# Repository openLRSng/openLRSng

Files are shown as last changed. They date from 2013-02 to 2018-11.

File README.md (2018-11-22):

openLRSng
=========

My fork of openLRS code (based on thUndeadMod of openLRS)

More information at http://openlrsng.org

CONFIGURATOR UTILITY / BINARY FIRMWARE NOTE:
============================================
  This software should be used in source form only by expert users, for normal use 'binary' firmwares can be uploaded and configured by free configuration software available for Windows/Mac/Linux from Chrome web store.

  http://goo.gl/iX7dJx

  Binary firmware images are also available from

  https://openlrsng.org/releases/

TRANSMITTER HW:
===============
  - TX_BOARD_TYPE 0 (Arduino Mini/nano 328 16MHz)
    - Flytron openLRS M1 (100mW) TX

  - TX_BOARD_TYPE 2 (Arduino Mini/nano 328 16MHz)
    - Flytron openLRS M2 (100mW)/M3(1W) TX
    - OrangeRX UHF TX unit

  - TX_BOARD_TYPE 3 (RX module acting as TX) (Arduino Mini/nano 328 16MHz)
    - Flytron openLRS RX v2
    - OrangeRX UHF RX
    - HawkEye openLRS RX

    - connect PPM input to 5th slot from left (channel 4)
    - button between ground and 4th slot from left (ch3)
    - buzzer via transistor on 3rd slot (ch2) (active high)

  - TX_BOARD_TYPE 4 (Arduino Mini/nano 328 16MHz)
    - openLRSngTX ('kha' or DIY based on ngTX schematics)
    - HawkEye OpenLRSng TX

  - TX_BOARD_TYPE 5 (RX as TX) (Arduino Mini/nano 328 16MHz)
    - DTFUHF/HawkEye 4ch/6ch RX

  - TX_BOARD_TYPE 6 (Arduino Leonardo)
    - DTFUHF/HawkEye deluxe TX

  - TX_BOARD_TYPE 7 (RX as TX)
    - Brotronics PowerTowerRX

  - RX_BOARD_TYPE 8 (RX as TX)
    - openLRSng microRX

RECEIVER HW:
============
  - RX_BOARD_TYPE 2 (TX module as RX) (328P 16MHz)

  - RX_BOARD_TYPE 3 (Arduino Mini/nano 328 16MHz)
    - Flytron openLRS RX
    - OrangeRX UHF RX (NOTE both LEDs are RED!!)
    - HawkEye OpenLRS RX

  - RX_BOARD_TYPE 5 (Arduino Mini/nano 328 16MHz)
    - DTFUHF/HawkEye 4ch/6ch RX

  - RX_BOARD_TYPE 7
    - Brotronics PowerTowerRX

  - RX_BOARD_TYPE 8
    - openLRSng microRX

  Receiver pin functiontions are mapped using the configurator or CLI interface.

SOFTWARE CONFIGURATION:
=======================
  Only hardware related selections are done in the openLRSng.ino (Arduino) or platformio.ini (VSCode/PlatformIO).

  Run time configuration is done by connecting to the TX module (which is put into binding mode) with serial terminal. For best restults use real terminal program like Putty, TeraTerm, minicom(Linux) but it is possible to use Arduino Serial Monitor too.
  Sending '<CR>' (enter) will enter the menu which will guide further. It should be noted that doing edits will automatically change 'RF magic' to force rebinding, if you want to use a specific magic set that using the command (and further automatic changes are ceased for the edit session).

  Datarates are: 0==4800bps 1==9600bps 2==19200bps 3==57600bps 4==125kbps

  Refer to http://openlrsng.org

UPLOADING:
==========
Use a 3v3 FTDI (or other USB to TTL serial adapter) and Arduino >= 1.0.

  o set board to "Arduino Pro or Pro Mini (5V, 16MHz) w/ atmega328" (yes it runs really on 3v3 but arduino does not need to know that)

  o define COMPILE_TX and upload to TX module

  o comment out COMPILE_TX and upload to RX

  o for deluxeTX "arduino boardtype" must be set to "Leonardo"

GENERATED FIRMWARE FILES:
=========================
Makefile generates TX/RX firmware files for each frequency 433/868/915 as well as all hardware types [RX/TX]-[#].hex.

The "*-bl.hex" files contain bootloader and can be used when flashing via ICSP.
  o 328p model (all but type 6) use optiboot bootloader and thus needs fuses set to: Low: FF High: DE Ext: 05.
  o type 6 uses 'caterina' and fuses should be set to: Low: FF High: D8 Ext: CB.

USERS GUIDE
===========

Please refer to http://openlrsng.org (->wiki)

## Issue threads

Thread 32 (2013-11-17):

Selecting Output Power via RC Channel?

TobiasBales, 2013-11-17:
After using switching from EzUHF to a hawkeye lrs system
using openlrsng there is one thing I am missing.
Being able to use a switch to select between 2 (or 3) output power modes.

Is there an interest in adding this and getting it into the main repo?
If so I would probably do that.

The idea is to have a 2 or 3 position switch (I would prefer 3) to switch between
200mW, 600mW and 1W which can be useful to recover the plane in case of a failsafe etc.

Any opinions on this?

csurf, 2018-01-09:
@mikeller
we could probably get this setup, but I'm not sure if it's worth it. I personally wouldn't have a need for this, but others might.

It appears that your multiproto has the ability to change RF power, so perhaps legacy users might find something like this useful. dunno...

thoughts?

mikeller, 2018-01-10:
Yeah, I think this has mostly been superseded by the Multiprotocol support. I think we should close this.

csurf, 2018-01-10:
agreed.

geofrancis, 2018-01-10:
Power switching is already supported by a switch on the module itsself.

marcmerlin, 2018-01-10:
@geofrancis and it doesn't work for what it's worth, at least if never worked for me.

mikeller, 2018-01-10:
@marcmerlin: It seems to be working well on the orangeRX modules - but you have to solder on your own switch for it.

These days, the most comfortable way for this is to use Multiprotocol, and use the menu on the TX to adjust your power.

geofrancis, 2018-01-10:
the problem is you cant change the PA power on the modules, your just changing the input to the PA, i made a module with adjustable power before, basically switching the PA between 3.3v and 6v, normally this would reboot the module but with a large capacitor it slowed down the voltage change enough that it could be switched on the fly.

Closed 2018-01-10.

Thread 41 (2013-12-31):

Improved beacon/buzzer idea

readerror67, 2013-12-31:
Beacon ET Phone Home

Idea:
Utilizing the 'call' button on an inexpensive handheld radio (Baofeng UV-5R for example) to trigger remote beacon and/or buzzer.

Implementation (This is under the assumption of a new battery backup, small 1s 300mah, more on this later):
1) RX loses PPM signal, enters failsafe then beacon mode.
2) In between 'beacons' the RX will listen on a specific channel (435.00MHz)
3) If the 'noise' or RSSI crosses a certain threshold, the beacon is re-transmitted within a short period of time after the 'call'.
4) Audible beep is fired off (using buzzer circuitry) after this beacon based on duration of the 'call', this is used to hone in on the location once you are somewhat close as the model may be in a bush not visible.

Benefits:
1) It would be much faster to get a bearing as to where to head direction wise since one can manually fire off the beacon, spin in circles until they feel they have a better idea where the model is located.
2) The audible 'beep' can be set on a threshold as to not waste power, if the 'call' is longer than 2 seconds, the buzzer circuitry is activated.

kh4, 2015-01-04:
I may give a shot at this today ;-)

kh4, 2015-01-04:
Implemented by 4669e8a

kh4, 2015-02-09:
Hmh the audible part needs to be done still...

csurf, 2018-01-05:
@readerror67
The 'ET'/interactive beacon was setup a long while back.
Can you go ahead and close this out?

Closed 2018-01-09.

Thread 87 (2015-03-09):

GPIO swap

stormjohn, 2015-03-09:
Forgive me I made this comment on a closed issue (#70). But if you will, I will repeat myself!
How common is the GPIO swap an issue? I have a Flytron M3 (1W) its struggling to make 100mW on my power meter with a 50 Ohm "dummy load" no matter what I try. I compiled with the latest 3.8 firmware.
Any help would be greatly appreciated.
Thank you.
Lyn.

kh4, 2015-03-09:
With correct hw type (2) selected the GPIO:s are proper the setting is only used for certain hardware types and is handled internally.

What powermeter you are using? Notably you should measure the 'peak' power not average since the transmission is 'pulsed'. For example with default settings the average power from Flytron M3 would be around 150mW. You can use the 'openLRSng_tester' to transmit continously.

stormjohn, 2015-03-10:
Thanks for the reply Kari.

I tested both with "Average" & "PEP" on my cheap SWR / PWR meter, ( my finances could not stretch to a Bird 43). Anyhow the Average is as I said 100mW and Peak is only slightly higher at 120mW! I don't think there is anything wrong with the meter as I tested my "Dragon Link" in the same manner and it's showing the expected 500mW output.
I did noticed the spectrum analyzer was giving a peak RSSI output of only 81 at 432MHz. This did surprise me as I adjusted the frequency in the configurator for the UK legal 458MHz band.
What I have also found even with a Diamond SRH771 antenna on the Tx I cannot use it. The Rx gives me an intermittent "blue" LED changing almost straight away to a solid "red" LED at just a few Cm's away. If the Tx was giving even a small output I surely should have had a reasonable signal at a few Cm's. I did find the best response was to fit a small omni pole to the Rx and the "dummy load" (the one that came with the "Dragon Link" for range testing) to the Tx. I could get >50 meters with full servo control and solid "blue" LED and no lost "packets". If I reverse the antennas i.e. put the "dummy load" on the Rx and the small antenna on the Tx I again loose any control at few Cm's with all "packets" lost (solid "red" LED).
Again any advice would be appreciated.

Lyn

fofi1, 2015-04-29:
Flytron's 1W transmitter uses only 3.3V supply for the RFM23BP. So the maximum Output Power is 350mW for this module.

Only at 6V it would deliver about 900mW of output power.

The RFM Modules only work great with Dipole antennas due to internal impedance matching to 50 ohm.

kh4, 2015-04-30:
You might have burned the RFM23 modules output stage, thus is quite common.

It can happen by no or bad antenna while it is transmitting or by static electricity charge to the antenna port. You can get RFM23BP modules for about 10 to 15USD.

stormjohn, 2015-06-29:
Hi Kari.

Sorry for the late response.

I would like to agree with you on this if it wasn’t for the fact that I have both the original Flytron and the HK orange “look alike” unit both rated at 1W. Both are giving me a similar output!

I have some experience using RF units and would like to think I have not powered them without the antenna fitted!

I now know that because of the on-board 3V3 supply I am at best only going to see 27dbm (Hope RF datasheet).

Both units are showing a similar reading on the power meter! That is nowhere near my “Dragon link” unit.

I understand if you are unable to devote time to this.

In the mean time I am completing a unit with a ATMega 328 and Hope RF RFM 23BP with the full 5V5 supply at the Vcc pin.

Kind regards

Lyn.

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

Timvrakas, 2015-06-30:
Just to let you know, you are not the only one having these problems... I
just finished a prototype run of USB dongle RFM23bp devices, and I cannot
get any range out of them! I can't tell if it's my inexperience or bad
luck, but they sure are finicky.
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

stormjohn, 2015-06-30:
Hi Tim.

Thanks for sharing.

I will let you know how I get on with the custom units.

Kind regards

Lyn

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

linuxslate, 2018-01-02:
Sorry;  I commented on the closed issue too.

I am building my own DIY hardware, and I am using BOARD_TYPE == 4, which has #define GPIO_SWAP.

I have GPIO0 connected to RX ON, and GPIO1 connected to TX ON. In other words, they are NOT Crossed. It is wired like I see everyone wiring RFM22B's.

Therefor I thought I did NOT need #define SWAP_GPIOS.

But then I looked at the code. In common.h, I see:

```
#ifdef SWAP_GPIOS
  spiWriteRegister(0x0b, 0x15);    // gpio0 RX State
  spiWriteRegister(0x0c, 0x12);    // gpio1 TX State
#else
  spiWriteRegister(0x0b, 0x12);    // gpio0 TX State
  spiWriteRegister(0x0c, 0x15);    // gpio1 RX State
```

The comments seem to indicate that if GPIO0 connected to RX ON, then I DO need SWAP_GPIO's.

Is the comment wrong or mis-leading?

Is 0x12 on or off? I have read the RFM23BP data sheet, and I still don't get it. Also, RX ON and TX ON are apparently active low.

Please help, as I have been messing with these both in software and hardware, and probably fried my module.  I have more on the way, but I do not want to install them without understanding this better.

--- Very confused.

linuxslate, 2018-01-02:
This is also unresolved in (Closed) issue 81.
https://github.com/openLRSng/openLRSng/issues/81

They are telling him to use BOARD_TYPE == 2, which does not have #define GPIO_SWAP, but both the schematic in that issue, and the photo show that the GPIO's are wired crossed (look at the feed throughs).

In the hopes of making this easy, I have even done some ascii art to try to make this clear.

```
If you have a RFM23BP, and the GPIO connections
are wired like this:

Looking at top (component side) of RFM23BP

 ______________
|   _______    |
|  |       |   |
|  |   |   |   |
G  G   V   R   T
P  P   C   X   X
I  I   C
O  O       O   O
1  0       N   N

Then DO/DO NOT use #define SWAP_GPIOS

If it is wired like this:

 __________
|   _______)___
|  |       |   |
|  |   |   |   |
G  G   V   R   T
P  P   C   X   X
I  I   C
O  O       O   O
1  0       N   N

Then DO NOT/DO use #define SWAP_GPIOS

```

If someone "in the know" could just edit it DO's/DO NOT's appropriately, it would really help.

This could even go at the beginning of hardware.h

csurf, 2018-01-02:
@linuxslate,
normal: GPIO0 ==>> TX pin
swapped: GPIO0 ==>> RX pin
so, add/remove the '#define SWAP_GPIOS' statement accordingly based on your connections.

the '0x12' & '0x15' values are binary/bitmap values meant to configure the GPIO registers in order to have them output the TX and RX states. These are fed into the TX_ANT and RX_ANT pins on the RFM module in order to put the antenna into either TX mode or RX mode.

See this datasheet for more info on register config:
https://www.silabs.com/documents/public/data-sheets/Si4430-31-32.pdf

csurf, 2018-01-05:
@mikeller
let's close this back out once @linuxslate responds with an 'ACK' for the above explanation...

linuxslate, 2018-01-05:
My DIY transmitter seems to be working with it wired like this:

```
______________
|   _______    |
|  |       |   |
|  |   |   |   |
G  G   V   R   T
P  P   C   X   X
I  I   C
O  O       O   O
1  0       N   N

```
... and #define SWAP_GPIOS  defined.

This seems to agree with csurf's explanation above.

So I am OK with closing this issue.  However; I think that the comments in the #ifdef SWAP_GPIOS section of common.h should be replaced with csurf's explanation:
```
normal: GPIO0 ==>> TX ON, GPIO1 ==> RX ON
swapped: GPIO0 ==>> RX ON, GPIO1 ==>TX ON
```
(Note that I changed the nomenclature to match the pin callouts in the RFM23BP datasheet.)

They should also be included as a comment at the top of hardware.h
The comment should probably include a line explaining that this is only for some boards with a RFM23BP.

Just suggestions.  I'm just a just a dumb user that likes to solder stuff and fly radio control.

csurf, 2018-01-05:
@linuxslate
ok, agreed, the comments will be added to hardware.h. I'll have to set it up on a separate 'hardware cleanup' branch where I'll start breaking up the hardware profile definitions into separate files.

BTW, @linuxslate, are you on IRC chat? You should come check out the  openlrs channel on freenode. It's pretty dead nowadays, but a few of us are still active on there sometimes, and it's easier to ask questions & discuss ideas there.

@mikeller
please grant me write access so I can start actively cleaning stuff up here on the repo...

linuxslate, 2018-01-30:
Believe it or not, there is still confusion on this.  See edited comment above.

Just updating for any DIY'ers or product designers that may still want to use this module.

jonathan2018, 2018-01-31:
#define SWAP_GPIOS. Wherecan   i can add it ?
#if (BOARD_TYPE == 3)
#if (__AVR_ATmega328P__ != 1) || (F_CPU != 16000000)
#warning Possibly wrong board selected, select Arduino Pro/Pro Mini 5V/16MHz w/ ATMega328
#endif

#if (COMPILE_TX == 1)
HardwareSerial *rcSerial = &Serial;

#define USE_ICP1 // use ICP1 for PPM input for less jitter

#define PPM_IN 8 // ICP1

#define TX_AIN0 A4 // SDA
#define TX_AIN1 A5 // SCL
#define TX_MODE1 11
#define TX_MODE2 12

#define BUZZER_ACT 6
#define BUZZER_PAS 3
#define BTN 7

linuxslate, 2018-01-31:
I am not sure *why* you would want to add it.
CAUTION:  Adding it can cause hardware damage.

If you are a DIY'er (Building or modifying your own hardware) you should correct the GPIO wiring, *not* add #define SWAP_GPIOS

If you are using a supported board, you should not have to add this, and if you do, hardware damage may result.

If you still feel you need to add it, it can be anyplace in the board definition, just make sure it is not inside of the #if (COMPILE_TX != 1)  #else structure, other wise you could end up with it defined for RX, and not for TX or vise-versa.  In this case, hardware damage would almost become a certainty because it will definitely be wrong for one.

The only board that uses it (== 4) puts it at the very end.

Closed 2018-01-09.

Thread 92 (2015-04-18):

Diversity doesn't switch

fofi1, 2015-04-18:
Hi,

After building and flashing my 2 Broversitys I recognized that the ANT_Detect Pin (PD7) stays low all the time. I have never seen it switching. Even if I disconnect the active Antenna it doesn't want to switch. It is the same with both Diversitys :( .

Is there any way to look up the rssi values of the two antennas? Is there any debug information i can use to look if the HF switch works correctly?

P.S: I'm very happy that Openlrsng now supports diversity (VERY VERY important when we fly down montains. Multipathing is extreme).

Have a nice day,
Florian from Germany

readerror67, 2015-04-19:
Hello Florian,

PD7 was actually put in place but is not actually used. I added it incase code was added to monitor the active antenna in OpenLRSng but this is not needed. R5 should not be populated as it will pull things down to ground.

There are also a few other troll parts that should be left unpopulated:
R9 - Resistor by LED (pulldown)
R18/R4 (Right under PPM)
R5 as covered above.

If you flash the BroversityRX firmware and have it bound the LEDs should both be blinking very quickly, it may look like they are both on but its actually switching between antennas during the pre-amble.

Also make sure you have diversity enabled on the TX, this will generate a slightly longer pre-amble which is used for the algorithm to select the best antenna.

fofi1, 2015-04-19:
Hi,

thanks for the fast response.  R5 is currently populated on my board. I will remove it and test it again next weekend.

Have a nice day :)

fofi1, 2015-04-29:
Hi,

With the removed Resistor R5 everything is working perfect. Thanks for your great support.

I hope i can make a rangetest tomorrow :)

Closed 2015-04-29.

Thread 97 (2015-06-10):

Taranis TX low power causing cleanflight receiver bar fluctuations

Ninjarev, 2015-06-10:
Dont know if anyone is having this problem..  When taranis transmitter drops to 7.8V using a LRS deluxe UHF transmitter module cleanflight has fluctuations in the channel bars in reciever tab. It gets worse as voltage drop gets lower. When it drops to 7.2V the UHF will not bind.  If I charge the radio back up to 8.4 volts it works fine..  Also note using a Sparky and the reviever is a mini DTF..

kh4, 2015-06-14:
Please check by having the TX module connected to PC while taranis is low power, open up the signal monitor tab an see if the bars are stable there.

Ninjarev, 2015-06-24:
Thanks for response I will check it next time battery is low

JIM

----- Original Message -----

From: Kari Hautio<mailto:notifications@github.com>

To: openLRSng/openLRSng<mailto:openLRSng@noreply.github.com>

Cc: Ninjarev<mailto:senshirev@msn.com>

Sent: Sunday, June 14, 2015 10:32 AM

Subject: Re: [openLRSng] Taranis TX low power causing cleanflight receiver bar fluctuations (#97)

Please check by having the TX module connected to PC while taranis is low power, open up the signal monitor tab an see if the bars are stable there.

—
Reply to this email directly or view it on GitHub<https://github.com/openLRSng/openLRSng/issues/97#issuecomment-111853262>.

csurf, 2018-01-09:
@Ninjarev,
did you ever get this tested and resolved? if so, please post back and close this issue out.

csurf, 2018-01-23:
no response, closing...

Closed 2018-01-23.

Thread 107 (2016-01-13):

speedup update freq by transmitting only changing channels

universam1, 2016-01-13:
AFAIK every channel is transmitted in order regardless whether its value has changed or not. Could we increase speed and/or range by transmitting only changing channels and submitting 'full' frames only from time to time?

The nature of RC is that during one cycle not all channels are going to change at once. Mostly maybe 2-3 channels only change, while other ch like AUX only in few seconds.

The idea is, regularly sent full frames, between only the changing ones.
I see following advantages:
- The active channels get automatically priority.
- Less channels altered the more bandwidth, up to almost full bandwidth for a single active channel
- it would be possible to transmit always all 16 channels, regardless if used or not, since they would take almost no air time!

For instance, every channel gets an ID, say 2-byte word with first 4 bits the address 0-15 and remaining 12 bit the value. The TX keeps track of last values and skips channels not changed. Of course on CPPM input there would be some trigger needed against jitter, but SBUS & co would be fine.
Every 500ms or so a full frame is sent to sync.
On RX side it would be a simple assigning of channels to array that do arrive.

If worst comes to worst, and the RX doesn't receive, probably this is not an issue, since as a pilot you would add more input if you are missing response which does implicitelly call a update fire of that channel.

What do you think about that?

Thank you!

mlyle, 2016-01-13:
There's a lot of delicate things that come into making a protocol which does this.  This isn't to say it can't be a win, but that it's nontrivial.

First, the receiver needs to be able to deterministically predict where the transmitter will be transmitting at a given time.  So the channel hop time needs to be predictable to the receiver no matter what the transmitter is trying to do.

Second, shorter frames are not always as much of a win as one might think, because of channel hop time, the preamble detector, etc.

Third, the effect of loss needs to be considered.  E.g. if someone clicks a "flight mode" switch which changes a FC from acro to attitude mode, and then immediately moves the pitch stick full forward, what are the consequences if the frame containing the "mode" change is lost but the pitch input is maintained?

ElectricRCAircraftGuy, 2016-01-13:
That's what I see too. The only way one can successfully implement what is
being proposed I think is to have two-way communication, where the receiver
responds to the sender with an acknowledgement packet, and the sender keeps
sending repeat information until the receiver acknowledges receipt of this
information. Otherwise, packet losses can be catastrophic. For one way
communication I don't see a way to avoid this hazard without sending every
channel every frame. This way,  lost packets have essentially no effect, as
the RC vehicle continues operating as commanded so long as the occasional
packet does get through.

Sincerely,

Gabriel Staples
www.ElectricRCAircraftGuy.com

(sent from my Android)
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

universam1, 2016-01-13:
Well, I dont think it is needed to change the hop time or change the frame lenght at all. I am thinking about to add a channel ID that helps the receiver determine which channel was sent. So no change needed to current transmission, just changing the data.

Also, the 'full frame' the one that contains all channels could be deterministically discovered or maybe even an adjustable setting. Or a fallback to 'syncronous' mode by the emergency button click...

Or, if we have 2-way communication, then sent back the CRC. If not correct, fall back to "syncronous" mode.

mlyle, 2016-01-13:
> Well, I dont think it is needed to change the hop time or change the frame lenght at all. I am thinking about to add a channel ID that helps the receiver determine which channel was sent. So no change needed to current transmission, just changing the data.

If you don't change the frame length, you'll be sending data at the present rate.  So what is the benefit from not sending all the channels?  Also the frame that contains all channels can be presumed to be longer...

universam1, 2016-01-14:
Indeed, the 5 bytes chunks made me think it is possible without altering the frame length which is obviously necessary...

I came accross this while working on FRSKY air protocol. Interestingly, that is actually what they're doing, sending active channels on a higher update rate than idle ones. Even more, they are also prioritizing more important telemetry frames. Obviously, it works.
They introduce a frame by a start and end byte + CRC, and channels by an ID. This is smart implemented, since it gives the TX full domain over what to send and how often, thus not requirering the RX to any special timing agreement.

Dont get me wrong, I dont want to propose FRSKY protocol nor mark OpenLRSng as not well done - I love to use OLRSng wherever possible, but I currently still prefer FRSKY for acro planes because of responsiveness.

Another benefit hence could be, that free airtime bandwidth could be granted between the serial data and the channels updates, dependent of needs.

I think it would be possible to lift OpenLRSng to a higher level with some airtime management like this.

DTFUHF, 2016-01-14:
That's interesting about the frsky protocol, I've looked at D8 and knew
they did telemetry scheduling due to the limited down link, but full frames
are sent on every uplink packet - same with PXX. Also - the frsky uplink is
only about 80Hz iirc, which makes PPM the bottleneck for system latency and
refresh - and openlrsng can easily beat

On Thu, Jan 14, 2016 at 4:47 AM, universam1 <notifications@github.com>
wrote:

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

universam1, 2016-01-14:
Not talking about the D8 or PXX  which is to the TX, but on the air code which is different.
You beat 80HZ update rate with the 19200 baud setting? I guess you mean 115200 baud that I would not consider stable.

DTFUHF, 2016-01-14:
I am referring to the over-the-air d8/16 protocol, working source can be
found in DeviationTX firmware.

From memory, openlrs at 19.2k, the 8 channel link is 71Hz, the 4+4 channel
link is higher

On Thu, Jan 14, 2016 at 7:14 AM, universam1 <notifications@github.com>
wrote:

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

universam1, 2016-01-14:
I checked, at 19200 with 8ch it is at 39hz, with 4+4 it is 42hz.
80hz would be a nice goal.
Am 14.01.2016 16:30 schrieb "DTFUHF" <notifications@github.com>:

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

DTFUHF, 2016-01-14:
Ah, right, I typically don't use telemetry :)

With telemetry off uplink rate is doubled.

On Thu, Jan 14, 2016 at 8:53 AM, universam1 <notifications@github.com>
wrote:

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

kh4, 2016-02-01:
I will keep this in mind if I do drastic changes to protocol.

As for now I am not going to do differential since it would mean differentiating the telemetry/nontelemetry modes significally.

Closed 2016-02-01.

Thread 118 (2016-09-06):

WIP: Serial PPM-in over native pins (PPMin)

universam1, 2016-09-06:
This is to give a heads up and request for guidance.

@mikeller and I are working successfully on adding Serial input with Multiprotocol, since the existing SUMD or SBUS protocols are facing dropping support on the controller side opentx/opentx/issues/2894
#### Multiprotocol via Hardware Serial

There is already a nice working and tested Multiprotocol implementation via the **HardwareSerial** port from @mikeller: openLRSng/openLRSng/pull/117
### Serial on native pins

The logical conclusion was whether it is possible to parse the native PPM-in pin via Software Serial which will bring benefits like
- **no soldering** required so plug and play
- configuration still accessible as before on the hardware serial
- no additional work then enabling digital transmission
- serial uplink still possible (APM f.e.)

It works! :smile:
After a lot of tuning and improvements as parity checks we are now up to 99.9% frame integrity!!
That means on 1/1000 frames there is one value "0" thus corrupt, this happens ~20sec. So far this is pretty awesome result given that it's Software Serial. (should be possible to filter this one frame out).

A working softserial implementation on its native pins you are welcome to test it here: **https://github.com/universam1/openLRSng/tree/Multi_with_SoftSerial**

Now I would appreciate some feedback where the stakeholder would like to go.
### custom "OLRS" protocol or Multiprotocol

As being said Multi over Softserial does already work 99.9% but there are some downsides of using Multiprotocol (changing standard to come, no ID for OLRS, no CRC). As of opentx/opentx/issues/2894#issuecomment-244875639 we could get integration in OpenTX with a custom protocol.
##### OLRS custom benefits:
- adding CRC gives SoftSerial 100% integrity.
- adding configuration data to **change values like Power or Telemetry on the field** without a PC hooked up.
- more efficient telemetry or data transmission
- not dependent to Multiprotocol changes (that are to come)
##### Multiprotocol benefits:
- already available on some firmwares like er9x
- reuse some config fields

Now I would appreciate some feedback where the stakeholder @kh4 @DTFUHF would like to go and what MR would be accepted.

Thanks

mikeller, 2016-09-06:
> adding configuration data to change values like Power or Telemetry on the field without a PC hooked up.

Already supported by openLRSng. Invention of a new protocol not necessary for this.

> more efficient telemetry or data transmission

Please explain how you plan to achieve this.

> not dependent to Multiprotocol changes (that are to come)

universam1, 2016-09-07:
> Please explain how you plan to achieve this.

Sure!
#### Multiprotocol #####
+ 8E2 = start + 8bit + parity + 2x stop => 12bit/byte
+ Frame : [sync][3x config][SBUS start][16x 11bit ch] => 27byte / frame

27byte x 12bit = 324bit/frame

#### custom Olrs prot ####
+ 8N1 = 10bit/byte
+ Frame:  [sync][2x config][ 16x 10bit/ch][CRC8] => 24byte / frame
( with 10bit we avoid unnecessary overhead in scaling 1000-2000 == 10bit)

24byte x 10bit = 240bit/frame

Therefore, custom protocol would be 324/240== __35% more efficient__

mikeller, 2016-09-07:
> Therefore, custom protocol would be 324/240== 35% more efficient

What exactly do we get from being 'more efficient' in terms of using less bandwidth on the part of the transmission that already has 5 times more capacity than the radio interface can transmit?

universam1, 2016-09-07:
Time! :)

Not true. Currently the update interval of Mulit is 22,5ms == 44Hz. Therefore, we are already missing and skipping on a transmission rate of >50 Hz that you are above when on 19200 w/o telemetry.

mikeller, 2016-09-07:
Not sure how you are getting to the 22.5 ms update interval, but it sure ain't caused by the bandwidth on the serial link, which allows for 187 bytes to be transmitted in 8E2 during this interval.

universam1, 2016-09-07:
Of course - the question is was how Multi is currently acting and what benefits a new protocol could enable.

csurf, 2018-01-10:
@mikeller,
is this discussion ongoing or resolved?

mikeller, 2018-01-10:
@csurf: Yes. Multiportocol support has been implemented and is supported by most TX firmwares.

Closed 2018-01-10.

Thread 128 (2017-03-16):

Serial conexion no possible without DTR signal

jpino1, 2017-03-16:
Hi,
From https://github.com/openLRSng/openLRSngWiki/wiki/Connecting-to-a-computer

"The following connections must be made between the device and USB-Serial adapter:

    Ground
    TX
    RX

If you are flashing the device, an additional pin is required: **(optional if simply changing settings)**

    DTR
"
I was perform several test and even the DTR signal is needed for communication, this is a problem for use BT module.
Any chance of disable the mandatory DTR signal for read/write settings with configtool?,It would be very interesting to use the BTmodule to change the settings.
I do not know if this affects sending the telemetry through the BTmodule I have to try it.
Thank you!

csurf, 2018-01-05:
@jpino1
The DTR pin is used to reset the ATMega328 in order to enter OpenLRSng's "BIND"/Configuration mode (this happens prior to booting up into 'normal mode'). This isn't something that's done by OpenLRSng code; it's a function of how the USB-to-serial connection is normally setup to the AVR. The reset signal is automatically sent to the DTR pin (for a standard FTDI USB-to-TTL serial adapter) upon connecting to the  USB COM port.

For connecting with a BT module, you'd have to do the following:
- connect your bluetooth module to the TX module via the serial connection
- manually power cycle the TX module while briefly holding down the 'BIND' button on the TX module in order to get it into 'bind mode' (continuous beeping, LED's flashing)
- try to connect from your PC to the TX module over bluetooth to the CLI with a terminal emulator such
as putty, or try to connect via the Configurator app selecting the correct COM port for your bluetooth connection

The key is to manually reboot the TX module and place it into BIND mode using the button on the TX since the bluetooth connection isn't able to automatically reset the TX module.

Please try this and post back your results.
If it works, please close out the issue, and consider adding a 'how-to guide' to the wiki so that others can  benefit as well.

jpino1, 2018-01-05:
Hi Csurf,
Thank you very much for the detailed information.
I need a little time to try what you tell me .
I post the results.
Thank you very much for taking the time to answer me.
regards
Jose A.

csurf, 2018-01-09:
@jpino1
please close this issue after you've tested and are satisfied with results.

jpino1, 2018-01-23:
Hi, csurf.
Work as you described, I will close the issue.
Thanks for the help and the great work.
Best  regards.

Closed 2018-01-23.

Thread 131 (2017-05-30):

1W Tx used as Rx without hardware modifications ?

mric3412, 2017-05-30:
Using a Tx module (BOARD_TYPE==2) as Rx without hardware modifications should be great.
Buzzer is used for the PPM output and PPM input (connection pin of the Tx module) is used for RSSI. Is it possible to use the PPM input pin for the PPM output instead of RSSI ? (I tried to modify hardware.h but it didn't work) This configuration would be great with the gitsly branch (symetrical link with mavlink for UAV)
PS : PPM output via the PPM_in pin works in UltimateLRS with wolfbox Tx modules (but it's not opensource).

csurf, 2018-01-05:
@mric3412
I will take a look at it as soon as I can...

csurf, 2018-01-05:
@mric3412
The reason for the buzzer pin being used for PPM output is due to how the pins are mapped on the OrangeRX 1W TX. The buzzer pin is the only available pin that's tied to the ATMega328's TIMER1. TIMER1 is used in OpenLRSng for both PPM and PWM generation. The PPM out pin is tied to TIMER2, which is used for RSSI and/or LBEEP signal generation within OpenLRSng. These things are hardwired into the MCU and cannot be changed. The PPM generation code would need to be completely redesigned in order to handle using TIMER2 which is an 8-bit timer (lower resolution than TIMER1 which is 16-bit).

In conclusion, sorry, but this isn't really feasible at this point without a major code rewrite. There are other, easier options for setting up a 1W RX. However, if you really must use an Orange TX module, you'll just have to deal with removing the buzzer and soldering in some jumper wires for the PPM connection.

Please close this issue out if you're satisfied...

mric3412, 2018-01-07:
Thank for your reply. I understand it would need to completely rewrite a lot of code. For those who don't want to risk to deteriorate their module, it's interesting to know that UltimateLRS software implements this feature. I have to precise that v1.x of ULRS is open source (I tested it successfully with two 500mW wolfbox modules) Moreover UART is used for MAVLINK link (Mavlink successfully tested with PC/Android GCS as missionplanner) Version 2.x of ULRS is not open source (but free)

Closed 2018-01-07.

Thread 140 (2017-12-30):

Add support for Anarduino MiniWireless22 board

csurf, 2017-12-30:
Add hardware profile support for 'Anarduino MiniWireless' modules based on RFM22B.
More info can be found here:
http://www.anarduino.com/miniwireless/

This would be setup as hardware type '10', and would include support for both a 'TX' and 'RX' profile.

Pin mappings & testing to be done by RCG user 'carcynic'.
If things get complicated, I will consider ordering a pair of boards myself in order to do some testing.

more info to follow...

linuxslate, 2017-12-30:
(linuxslate is RCG user 'carcynic'.)

You can see a picture of my Anarduino-22-433-based receiver in this post:
https://www.rcgroups.com/forums/showpost.php?p=38892572&postcount=9465

Here is my wiring:
```
SDO	D12
SDI	D11
SCK	D13
NSEL	D10
NIRQ	D2
SDN	D4

PPM IN (TX)	None (Can be D8)
LED 1 (Red)	D9
LED 2 (Green)	None
Button		None
Buzzer		None

PWM 1		A2 also PPM
PWM 2		A4 also SDA
PWM 3		A3 also RSSI
PWM 4		A4 also SCL
PWM 5		A0
PWM 6		A1

```

linuxslate, 2017-12-30:
Here is a stab at a (BOARD_TYPE == 10) // Anarduino-22-433 as RX.

Only worrying about RX at this time, but there is no reason not to leave the TX code in there.

I'm not a "real" Atmel programmer, so this is going to need some help.

```
#if (BOARD_TYPE == 10) // Anarduino-22-433 as RX
#if (__AVR_ATmega328P__ != 1) || (F_CPU != 16000000)
#warning Possibly wrong board selected, select Arduino Pro/Pro Mini 5V/16MHz w/ ATMega328
#endif

#if (COMPILE_TX == 1) // TX operation

HardwareSerial *rcSerial = &Serial;

#define USE_ICP1 // use ICP1 for PPM input for less jitter
#define PPM_IN 8 // ICP1

#define TX_AIN0 A4 // SDA
#define TX_AIN1 A5 // SCL

#define TX_MODE1 A1
#define TX_MODE2 A2

#define BUZZER_PAS 3 // OCR2B
#define BTN A0

#define RF_OUT_INDICATOR A3 // only used for Futaba

void buzzerInit()
{
  TCCR2A = (1<<WGM21); // mode=CTC
#if (F_CPU == 16000000)
  TCCR2B = (1<<CS22) | (1<<CS20); // prescaler = 128
#elif (F_CPU == 8000000)
  TCCR2B = (1<<CS22); // prescaler = 64
#else
#errror F_CPU Invalid
#endif
  pinMode(BUZZER_PAS, OUTPUT);
  digitalWrite(BUZZER_PAS, LOW);
}

void buzzerOn(uint16_t freq)
{
  if (freq) {
    uint32_t ocr = 125000L / freq;
    if (ocr>255) {
      ocr=255;
    }
    if (!ocr) {
      ocr=1;
    }
    OCR2A = ocr;
    TCCR2A |= (1<<COM2B0); // enable output
  } else {
    TCCR2A &= ~(1<<COM2B0); // disable output
  }
}

#else
// RX operation

#define PPM_OUT A2 // A2
#define RSSI_OUT A3 // A3

#define PWM_1 A2 // 0 PC1 - also PPM
#define PWM_2 A4 // 1 PC4 - also SDA
#define PWM_3 A3 // 2 PC3 - also RSSI
#define PWM_4 A5 // 3 PC5 - also SCL
#define PWM_5 A0 // 4 PC0
#define PWM_6 A1 // 5 PC1 - Buzzer

#define OUTPUTS 8 // outputs available

const pinMask_t OUTPUT_MASKS[OUTPUTS] = {
  {0x00,0x04,0x00}, {0x00,0x10,0x00}, {0x00,0x08,0x00},// CH1/PPM, CH2/SDA, CH3/RSSI
  {0x00,0x20,0x00}, {0x00,0x01,0x00}, {0x00,0x02,0x00},// CH4/SCL, CH5/PWM, CH6/PWM
  {0x00,0x00,0x01}, {0x00,0x00,0x02},                  // CH7/RXD, CH8/TXD - only on 6ch

};

#define PPM_OUTPUT 0
#define RSSI_OUTPUT 2
#define ANALOG0_OUTPUT 1 // actually input
#define ANALOG1_OUTPUT 3 // actually input
#define SDA_OUTPUT 1
#define SCL_OUTPUT 3
#define LLIND_OUTPUT 5
#define RXD_OUTPUT 6
#define TXD_OUTPUT 7

const uint8_t OUTPUT_PIN[OUTPUTS] = { A2, A4, A3, A5, A0, A1, 0, 1};

struct rxSpecialPinMap rxSpecialPins[] = {
  { 0, PINMAP_PPM},
  { 1, PINMAP_SDA},
  { 1, PINMAP_ANALOG}, // AIN0
  { 2, PINMAP_RSSI},
  { 2, PINMAP_LBEEP},
  { 3, PINMAP_SCL},
  { 3, PINMAP_ANALOG}, // AIN1
  { 5, PINMAP_LLIND},
  { 6, PINMAP_RXD},
  { 7, PINMAP_TXD},
  { 7, PINMAP_SPKTRM},
  { 7, PINMAP_SBUS},
  { 7, PINMAP_SUMD},
};

void rxInitHWConfig()
{
  rx_config.rx_type = RX_OLRSNG4CH;
  rx_config.pinMapping[0] = PINMAP_PPM;
  rx_config.pinMapping[1] = PINMAP_ANALOG;
  rx_config.pinMapping[2] = PINMAP_RSSI;
  rx_config.pinMapping[3] = PINMAP_ANALOG;
  rx_config.pinMapping[4] = 4;
  rx_config.pinMapping[5] = 5;
  rx_config.pinMapping[6] = PINMAP_RXD;
  rx_config.pinMapping[7] = PINMAP_TXD;
}
#endif

#define Red_LED 9 // D9 PB1
#define Green_LED 5 // D5 PD5

#define buzzerOff(foo) buzzerOn(0)

#define Red_LED_ON  PORTB |= _BV(1);
#define Red_LED_OFF  PORTB &= ~_BV(1);

#define Green_LED_ON   PORTD |= _BV(5);
#define Green_LED_OFF  PORTD &= ~_BV(5);

#define RF_OUT_INDICATOR A3 // only used for Futaba

//## RFM22B Pinouts for Public Edition (M2)
#define  nIRQ_1 (PIND & 0x04)==0x04 //D2
#define  nIRQ_0 (PIND & 0x04)==0x00 //D2

#define  nSEL_on PORTB |= (1<<2) //B2
#define  nSEL_off PORTB &= 0xFB //B2 Need help with value here

#define  SCK_on  PORTB |= _BV(5)  //B5
#define  SCK_off PORTB &= ~_BV(5) //B5

#define  SDI_on  PORTB |= _BV(3)  //B3
#define  SDI_off PORTB &= ~_BV(3) //B3

#define  SDO_1 (PINB & _BV(4)) == _BV(4) //B4
#define  SDO_0 (PINB & _BV(4)) == 0x00  //B4

#define SDO_pin 12
#define SDI_pin 11
#define SCLK_pin 13
#define IRQ_pin 2
#define nSel_pin 10
#define SDN_pin 4

void setupSPI()
{
  pinMode(SDO_pin, INPUT);   //SDO
  pinMode(SDI_pin, OUTPUT);   //SDI
  pinMode(SCLK_pin, OUTPUT);   //SCLK
  pinMode(IRQ_pin, INPUT);   //IRQ
  pinMode(nSel_pin, OUTPUT);   //nSEL
}

#define IRQ_interrupt 0
void setupRfmInterrupt()
{
  attachInterrupt(IRQ_interrupt, RFM22B_Int, FALLING);
}

#endif

```

linuxslate, 2017-12-30:
Note also:

Above code edited to change:
`x_config.rx_type = RX_ANARDUINO_6CH`

Add:
`#define RX_ANARDUINO_6CH 0x09`

To the top.

In dialog.h, add:
```
else if (rx_config.rx_type == RX_ANARDUINO_6CH) {
    Serial.println(F("Anarduino-22"));
  }
```

mikeller, 2017-12-30:
This looks like an exciting new option. Thanks for putting in the effort to add this, @linuxslate.

Would you be able to open a pull request for these changes?

linuxslate, 2017-12-30:
Currently, with the above code, I can bind, and connect through the TX to the RX on the configurator.  I can configure the RX, and it retains the configuration, but I do not get any servo movement.

(I know I have to disconnect from the configruator) to get servo movement.  I don't have a O-Scope anymore so I cannot see what is going on on any of the pins.

I am wired directly from the Anarduino lines to the servo connector pins.

linuxslate, 2017-12-30:
@mikeller ;

I am not a git pro, but I can try.

mikeller, 2017-12-30:
@linuxslate: No problem. There's people here who can help. :-)

csurf, 2017-12-31:
@linuxslate,
once you get something closer to a final product, let me know, and I can setup branch on my repo so that we can do the pull request from it.

As far as testing the outputs, first see if you can get PPM output working, and forget about trying to get the PWM outputs working. Send the PPM output to a flight controller and use the FC's config software to inspect the PPM signal. You could also look into setting up a software o-scope using your PC's soundcard via the line-in/microphone input. There are plenty of guides online on how to do this...

I noticed the anarduino has an RTC IC and flash memory. That might be pretty cool to use for RX stats logging (something I've messed with in the past).

linuxslate, 2018-01-01:
Good idea about using a Flight controller.  I kinda got out of the quad racing thing, so it's been a while since I messed with those types of Flight Controllers, but I think there is a loose one around here someplace, or I will have to enlist what remains of my 250 racer to help me.

It's is interesting that it seems to bind.  Even connected to a terminator, it will bind and configure from one end of the house to the other, but after it binds, nothing happens.

I enabled #define DEBUG_DUMP_PPM, and I get nothing after "entering normal mode" (Receiver connected to minicom.)

csurf, 2018-01-01:
@linuxslate
yeah, that was going to be my other suggestion: to try turning on the serial debug for the PPM signal. The fact that you're not seeing anything makes me wonder if the board isn't somehow crashing/hanging, or perhaps the TX is bombing and not actually sending any RC data over. You might want to have a look at the TX side first and make sure that things are setup correctly. Can you see valid channel data in the signal analyzer within the Configurator app?

linuxslate, 2018-01-01:
I do not see any significant peaks in the configurator Spectrum Analyzer.  The TX does not seem to transmit when I go to that tab.

Should the SA tab work without a receiver?  Should I see hop spikes without a PPM input to the TX?
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
linuxslate, 2018-01-22:
Sorry;  Edited above several times.

Anarduino used as an openLRSng receiver ends up being really similar to BOARD_TYPE == 5, but it still needs a separate BOARD_TYPE == 10 because the RFM22 pins are hardwired and are different than BOARD _TYPE == 5.

New wiring table and code to follow shortly.

mikeller, 2018-01-22:
> The Anardino has an internal (Red) LED connected to D9, but this does not interfere with it's use for a PPM Output. The LED in effect becomes a PPM/PWM activity indicator. (See -- It's a feature!)

I like that. :-D Also, you now can use the red led for an optically attached slave tx. ;-)

> I am not sure if opening another issue for dead code in hardware.h is constructive, or just complaining. Since I don't own the other hardware to test it, I cannot really "fix" all of the other boards.

I suspect that this is a big part of the reason why `hardware.h` is such a mess - changes will be difficult to test by any one person due to lack of having access to all of the hardware modules.

linuxslate, 2018-01-22:
> I like that. :-D Also, you now can use the red led for an optically attached slave tx. ;-)

Not sure about that, but you do bring up a good point.  Given the size and cost of the Anarduino, It almost does **not** make sense **not** to use it in a diversity arrangement.

fiveangle, 2018-01-22:
> I suspect that this is a big part of the reason why hardware.h is such a mess - changes will be difficult to test by any one person due to lack of having access to all of the hardware modules.
W/o an easy solution, perhaps we could open an issue where we keep a list list of testers with appropriate HW 🤷‍♂️
https://github.com/Brotronics/subMicroLRS (Type 5)
https://github.com/openLRSng/openLRSngWiki/wiki/HawkEye-DTF-UHF-JR-Deluxe-TX-module (Type 4)

mikeller, 2018-01-22:
Good point, @fiveangle!

csurf, 2018-01-22:
+1 vote for a 'hardware testers' issue/thread

I'm not to familiar with github, but it would be great to be able to setup some kind of automated build script that automatically notifies a 'tester group' that there's a fix/patch/PR that needs to be tested for there hardware. Not sure if this is possible through github, but something like this would be pretty cool.

linuxslate, 2018-01-23:
Updated Wiring:
* = Hardwired on Anarduino-22-433

```
SDO	D12*
SDI	D11*
SCK	D13*
NSEL	D10*
NIRQ	D2*
SDN	D4*

PPM IN (TX)	None (Can be D8 - 2.2K Resistor on Input Recommended.) *On Board LED
LED 1 (Red)	D6 (Optional - Add 220 Ohm Resistor and LED)
LED 2 (Green)	D7 (Optional - Add 220 Ohm Resistor and LED)
Button		None
Buzzer		None

PWM 1		D9 also PPM
PWM 2		A4 also SDA
PWM 3		D3 also RSSI
PWM 4		A4 also SCL
PWM 5		A0
PWM 6		A1
```
RX Data   D0 (*FTDI RX)
TX Data   D1 (*FTDI TX)

mikeller, 2018-01-23:
Thanks @linuxslate. We are currently having some discussion about moving to a better way of maintaining the definition for the different hardware targets (#139). I think the best course of action for this new target is to wait until we've concluded this discussion, and implemented the outcome (better structured hardware definitions), before we are adding a definition for your new target. No point in clobbering the new target into `hardware.h`, only to then have to spend more time separating it out again. If you want to provide testers with a version of your target, you can always do so by posting a (zipped) test build for it.

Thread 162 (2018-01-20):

USB issue with 32u4 builds with latest Arduino versions

csurf, 2018-01-20:
There's a problem with how Arduino versions post 1.06 are compiling code for the 'leonardo' 32u4 target that causes the chrome API to fail to detect the 32u4 as a valid USB device. The VID and PID look the same as before, but, for some reason, chrome can't pick it up. Currently, the only work-around is to use Arduino 1.06, but we should probably try to figure out exactly why this is happening.

FYI, this is for hardware type 6, the @DTFUHF deluxe 1W TX...

@mikeller, do you have any experience with the 32u4?

mikeller, 2018-01-20:
No, I don't. Have you tried on linux? `dmesg` output is usually quite verbose for USB device detection.

csurf, 2018-01-20:
I did some simple testing both on linux and windows.
haven't looked at dmesg output, just lsusb output, and things looked pretty much the same between the older Arduino 1.06 builds and the newer 1.6/1.8 builds. I'll try to take a closer look at it on linux though.

Timvrakas, 2018-01-20:
I had a similar USB radio prototype last year that used the 32u4 and I can confirm the USB can behave oddly. I ended up widening the USB traces for better impedance matching, but even then there were some issues.

csurf, 2018-01-20:
@Timvrakas
interesting find...

In this case, it definitely appears to be a software issue. Something within the Arduino USB code for the Leonardo changed between the legacy 1.06 version and the newer versions that's causing issues with chrome.

yes, the 32u4 is very finicky when it comes to USB compatibility. Unfortunately, there's still a lot of DTF UHF units that are running it, so we must continue to support it.

csurf, 2018-01-21:
@mikeller
ok, it seems that the newer 1.6/1.8 Arduino code *does work on linux. The chrome API doesn't have any issue with detecting the 32u4 as a USB device with builds based on either the newer or older libraries.

Firmware builds based on the 1.6/1.8 Arduino libraries don't work with the chrome USB API on the Windows 10 machines I've tested. The devices show up as valid COM ports within Windows / Device Manager, and even within chrome; chrome is able to open the port and communicate with it.

However, for some reason, chrome can't detect the device as being a 32u4 based on the PID and VID. The Configurator code relies on being able to detect the 32u4 using `chrome.usb.getdevices()` call in order to initiate the reboot sequence that's specific to the 32u4.

The are some noticeable differences in the Arduino USB core code between the 1.0.6 and 1.6+ versions. The main thing I can see is that the older lib's include HID support, which sets up the Leonardo as a USB HID device. The built-in HID functionality was removed in the newer libs. I'm guessing this might be clue as to why chrome can't pick it up...

mikeller, 2018-01-21:
Setting the device up as a USB HID device if it's nothing like an input device sounds like a very bad idea in any case, and should probably be removed.

Just one thing I can think of that is completely broken for fake USB HID devices is that they are unusable in virtualised operating systems (because forwarding them to the guest OS as raw device isn't supported).

csurf, 2018-01-21:
I agree that the HID functionality is not necessary, but perhaps just the fact that it's presented to the Windows OS as a HID makes chrome able to use it? not sure...

In any case, the current working builds already have the HID support built in, as the 1.0.6 libs already have it integrated into the USB code for the Leonardo.

Obviously, if there's a way we can remove HID and still get the newer libraries to work, then that would be preferable...

I'm also looking at the Arduino USB code and seeing if maybe there might be an issue with how the USB descriptor data is setup and sent to the OS. Maybe there's an issue with how the new libs present the device to Windows that causes issues with chrome.

FYI, the Windows & linux testing I've done has been with actual hardware installs and not VM's; I've also found that USB hubs can sometimes cause issues, so I've had to test with USB ports that are directly on the machine. It seems the 32u4 chips are quite a headache in terms of USB support...

mikeller, 2018-01-21:
> FYI, the Windows & linux testing I've done has been with actual hardware installs and not VM's; I've also found that USB hubs can sometimes cause issues, so I've had to test with USB ports that are directly on the machine. It seems the 32u4 chips are quite a headache in terms of USB support...

I've seen some USB hubs that are emulating their own set of (virtual) HID devices, and then forwarding the input from any actual HID devices plugged into them through those HID devices. This will be another use case where application support for devices registering themselves as HID devices will break...

csurf, 2018-01-22:
It appears that chrome does, in fact, rely on the HID interface for the `chrome.usb.getdevices()` system call to work.

The good news is that I've found a work-around, which is to instead enumerate the serial devices using `chrome.serial.getdevices()` in order to check & see if the current serial port is an ATMega32u4 device (based on PID and VID). After testing, this has proven to work reliably on all platforms and for both the older and newer Arduino libs. See the above PR for more details...

Will close after allowing some time for final testing and merging the PR.

mikeller, 2018-01-22:
Good work, @csurf!

Closed 2018-01-23.

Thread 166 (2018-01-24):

Diversity receiver

madhunm, 2018-01-24:
Is the diversity receiver being revived as well?

csurf, 2018-01-24:
The diversity code is still functional.

However, this is just the code repo, for the development of the firmware code. Hardware is completely separate. You'll have to look around online to see if anyone still sells the diversity RX's, or make one yourself...

madhunm, 2018-01-24:
@csurf i made the broversity receiver hardware. However, the antenna switch used in that design is obsolete. If there is interest in the hardware, I can make a new version. Let me know.

fiveangle, 2018-01-24:
What would be really exciting is full master/slave RX diversity that would not be tied to only very specific HW.   And since we're tossing coins in the wishing well, to do it with a serial RX as small as these again 😄: https://github.com/Brotronics/subMicroLRS

csurf, 2018-01-24:
@fiveangle
we actually just recently commented out the 'slave mode' code since we figured that no one was actually using it. You can still enable it by modifying the openLRSng.ino file and uncommenting the `define ENABLE_SLAVE_MODE` directive.

@madhunm
what do you mean when you say that the antenna switch is obsolete? So, are you saying that you actually designed the diversity receiver? I had assumed that user 'ReadError'had designed it...

madhunm, 2018-01-24:
@csurf  I am not the original designer. It was designed by brotronics and licenced to someone else for manufacture.

What I'm saying is that there's a hardware antenna switch that's obsolete and beds to be redesigned.
@fiveangle  like this ?
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

csurf, 2018-01-24:
@madhunm
ok, I see.
You're saying that the RF switch is EOL and no longer available (or difficult to acquire). That means that a new, different RF switch would have to be chosen, and the RX design would need to be updated. There is probably a newer model of the IC that can be used as a drop-in replacement. If not, the design will have to be modified to use a different RF switch.

In any case, this is beyond the scope of this repo. You're probably better off contacting @readerror67, and/or leaving an issue on the Broversity RX repo here on github. He can help you figure out what newer RF switch to use, and/or can probably help with upgrading the design.

madhunm, 2018-01-24:
@csurf I raised this issue to understand if there was an interest in a dedicated diversity receiver. If there is none, we can close this issue and then carry on.

However, if there is interest, then I'll wear my thinking cap.

Let me know.

csurf, 2018-01-24:
@madhunm
I'm a bit confused.
The diversity functionality is something that's already built into the RFM22 RF module. It just needs to be enabled in code. and it requires the external RF switch to actually do the phsyical switching of antennas.  Any new diversity receiver designs that are based on the RFM module will function in basically the same way. The only differences would be in the RF switch IC that's used and on the basic circuit layout & pin mapping.

However, on the software side, there's not much left to do, as the diversity support has already  been coded.

I see that you opened an issue on the Brotronics repo. That's a good first step to getting the design updated.

FYI, the general goal of this project is to start looking at upgrading the MCU from the ATMega328 to something more modern and powerful (STM32 or something similar). So, in general, I wouldn't recommend investing very much time, energy, or money in trying to focus on the older ATMega328 designs, unless you're really happy with those designs.

atomiclama, 2018-01-24:
Can someone clarify is this please
Reciever diversity as I think used when #define ENABLE_SLAVE_MODE is set.

or

Antenna diversity where the external RF switch is required.

csurf, 2018-01-24:
@atomiclama
the `ENABLE_SLAVE_MODE` configuration is used for enabling the DIY diversity using two separate RX modules connected to each other over i2c. You need to enable this in the code and recompile it yourself.

antenna diversity support is built into the standard code, but it requires a diversity receiver like the brotronics broversity receiver (i.e., a receiver with a single RFM22B module, yet with an RF switch IC that switches between two antennas/two SMA connectors).

mikerc2017, 2018-01-24:
yeah . move to stm32 and diversity . Great

i wonder , version 868mhz also work OK if use diversity ?

rodizio1, 2018-01-27:
Solutions with switches always suffer from several problems:

Isolation, explained here by Thomas Scherrer:
https://youtu.be/C6ZygOeCwLU?t=10m10s

And the general problems that occur with packet/preamble detection, preamble, switching over quickly enough, that's not easy to get right (The Atheros 722n cards used for wifibroadcast for example also have this problem, under certain conditions, the switch doesn't work right and packetloss occurs although the signal is good with only one antenna).

Easiest and best is to use two complete seperate RF paths and simply collect all packets on both RF modules or receivers and throw away the dupes (and make sure out-of-order delivery doesn't occur or is re-ordered ...).

geofrancis, 2018-01-31:
if we went down the route of dual modules for diversity that would also open up the idea of dual transmitter modules, you could run on 2 frequencies simultaneously either dual 433 or 868 or perhaps a mix? for a fully redundant RC system.

mlyle, 2018-01-31:
If you're doing dual receivers, and you have any kind of FEC, you can receive data on both sides-- if a packet decodes on neither, you can combine them and treat any differing bits as known-erasures.  Of course, this requires the same data be transmitted to both or they be on the same frequency.

linuxslate, 2018-02-01:
I know that we are trying to get away from the RFM2x modules (and I agree that we should), but I would like to point out that two Anarduino-22-433's could make for a small, light, and cost effective "true" diversity setup with (mostly) existing code. (Ref #140, my efforts to get Openlrsng working on the Anarduino-22-433).

I'd be willing to help, but due to #124 and #87/#70, it has already taken me 6 RFM2x modules, and I do not have a flight worthy TX/RX set yet.

If I end up with extra working modules (Complete Anadruinos in this case - not just RFM22B's), (or if someone would like to do a group buy), I'd be willing to try to assemble 2 Anarduino's into a R/C receiver like unit.

I just can't keep doing weekly Hope US/Anarduino orders.  (Note that it is not so much a financial thing;  It's more just embarrassment.)

mikeller, 2018-02-01:
@linuxslate: I wonder if it would work to run the modules with a current limiting device (aka smoke stopper), or to add a heat spreader to the power amp IC?
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
artemen, 2018-02-15:
@madhunm
It will be relatively easy to rework PCB for https://www.mouser.com/ds/2/472/SKYA21012_203021B-875861.pdf

control logic is the same, footprint and pinout are different, up to 32dbm RF power handling and OK isolation rating of 22-24db for our frequencies.

or this one (better):
https://www.mouser.com/ds/2/196/Infineon-BGSA12GN10-DS-v02_10-EN-1225430.pdf
same conrol logic, needs clean 3.3v, which is present via onboard LP5907.  It has better insertion loss (less than 0.25db under 500mhz), up to 39dbm power handling and 30db isolation between RF ports.

mikerc2017, 2018-02-16:
@Arteman
i like a rf switch 6 pin, smaller than orginal rx diversity brotronic .
even i will try use a rf swith availble  on rfm22 pcb

i flight with mono anten on Rx 100mw but only 400m with telemetry
 Tx 1w. Maybe this  is time to move to divesity

mikerc2017, 2018-02-16:
@arteman
which anten that you used on modul tx ?

madhunm, 2018-02-16:
@artenen

The chips you looked to are tiny! I mean, I'm sure they will disappear if you breathe on them sideways...

I'm partial to the skyworks chip; let me know your thoughts.

Thanks,

mikerc2017, 2018-02-20:
if use diversity for rx with modul 1w .How is it ?
i saw on tbs rx used two modul sx1272 for diversity . So which is diversity better ?  diversity use Rf switch or diversity two modul ?

artemen, 2018-02-20:
I've made a design for it a few years ago, but came to conclusion that there are no real benefits.  if you really need a bidirectional link, than just use commercial 900mhx WAN equipment for true single frequency rc/video/telemetry link. the prices are less than dragonlink for ubiquity equipment, just need antenna tracker  for ground part.

for hobby, one more high power transmitter on a vehicle which is already cramped up with equipment is just asking  for trouble, diversity or not.

I also have a smallish very basic diversity :

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

mikerc2017, 2018-02-20:
thanks artemen

design pcb good

jack113113, 2018-03-05:
hello  artemen

version diversity brotronic  also will work with modul 868mhz ?

artemen, 2018-03-05:
@jack113113
I am, not the correct person to ask, though I do not see a reason why not as long as you compile the source properly.

jack113113, 2018-03-06:
thanks Artemen .  So i will try it

artemen, 2018-03-06:
Btw, all of the openLRS RX designs badly need filtering of power source just before the RFM22/23 here is a video of how the offthe shelf hawkeye 9ch RX, delux v1 TX and my own version of 1W TX affected by noise on power supply. The last one shows sensitivity below -114db while delux v1 at -100db and 9ch Rx at about -108db. In the cvideo there is a short gain in sensitivity of delux v1 when I accidentally touched antenna with my hand. https://photos.app.goo.gl/X3Y9YHd3bG67J29x1

jack113113, 2018-03-06:
thank for infor

and i move to version 868mhz because   i want to use short anten on quad , hope Diversity work OK .
i wonder , Add a balun or filter input anten 868mhz will better ?

artemen, 2018-03-06:
The specific instance I mentioned is about inability of RFM22/23 along with onboard LDO to filter out noise on power line. RF side is actually sufficiently filtered and 50ohm matched, so no need for additional filtering.

jack113113, 2018-03-06:
thank   artemen

mikerc2017, 2018-03-14:
hi artemen

do you have same problem  same me ?  warring sensor lost when use betaflight telemetry One Uart ?

see video problem here https://www.youtube.com/watch?v=hT0vUbQawso

artemen, 2018-03-14:
Sorry i use frskyd and fly only APM hardware, so can't comment on multiprotocol.

mikerc2017, 2018-03-15:
artemen
mean you only use  RSSI  and 2 analog  in frsky D ?? i wonder in RX diversity brotronic  , Have not 2 analog ???

artemen, 2018-03-15:
@mikerc2017
i use frskyd output from PX4 family of FCs, it includes voltage, current, GPS, flight mode, GPS coord,  number of GPS sats, altitude, velocity and rssi.

mikerc2017, 2018-03-15:
thanks
i do not know why my TX alway warring lost sensor , sometime wrong value From FC betaflight . Can not fix this problem in long time

geofrancis, 2018-03-16:
The sensor lost warning happens if a sensor is not updated after 5 seconds.

jack113113, 2018-06-01:
@artemen , i wonder about rf switch
You  said  : this one (better):
https://www.mouser.com/ds/2/196/Infineon-BGSA12GN10-DS-v02_10-EN-1225430.pdf
same conrol logic, needs clean 3.3v, which is present via onboard LP5907. It has better insertion loss (less than 0.25db under 500mhz), **up to 39dbm power handling and 30db isolation between RF ports.**

what mean ?  RF switch increase sensitivy  ?

madhunm, 2019-12-27:
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

@artemen I know this is a very old thread; considering this is still open, do you think you could share the diversity board and schematics?

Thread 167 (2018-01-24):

Discussion: Port to STM32

atomiclama, 2018-01-24:
@csurf mentioned in #166 about plans to port to the STM32 platform so I though I'd open this issue to share the work I have done in this area and too see if there is any interest in using it.

So here goes a bit of brain dump ;-)

I have used Betaflight for the base code as this is what I'm familiar with, I have ported the rfm22 radio stack over to us the rx_spi model in betaflight. I'm currently using Nucleo dev boards with a hardwired rfm22 module on it.
I have a virtual comport implementation that can route the serial on the FC to the serial on the TX so I can use the CLI MSP or any of the telemetries, this is working ok for small packets but MSP is a bit kack.
I have RC control working where the TX side uses the internal RCdata and transfers it over to the FC so it can use any of the betaflight supported RX, so Sbus iBus ppm pwm etc and be used to control the model. I'm currently building it into a quad to see what it feels like.

There is plenty more todo, I only work on this from time to time, so it has been slow progress.

The plan was to get it up and running on
https://www.banggood.com/OpenPilot-OPLINK-MINI-CC3D-REVO-Universal-Transceiver-TX-RX-Module-Integrating-Remote-Controller-p-1000081.html
And
https://www.banggood.com/OpenPilot-CC3D-Revolution-Revo-10DOF-STM32F4-Flight-Controller-Staight-Pin-p-1000068.html

mlyle, 2018-01-24:
Note that we have -- somewhat messy-- openlrsng receiver code running in dRonin.

mikeller, 2018-01-24:
@atomiclama: Would you consider opening a pull request to add the openLRSng SPI RX to the Betaflight codebase? This would be a great addition to Betaflight's growing list of supported SPI RX!

The 'RX passthrough' mode that you are proposing (if I understand you right) is another great idea, and I think we can make this into something that can be added to the official Betaflight code base as well.

atomiclama, 2018-01-24:
Yes that is my intention. But at the moment the code is just concept and needs some tidy.

Also it is just the RFM22 level, the higher openlrs stack channel hopping etc is not implemented.
Didn't like the way the RC data was mashed up to shorten the packet length, there are unused bytes in there that can be removed to achieve the same.

Guess I need to do a bit of a write up

csurf, 2018-01-24:
@atomiclama,
which unused bytes in RC data packets are uou referring to? just curious...

atomiclama, 2018-01-24:
@csurf my mistake thought there was an saving in the config of register 0x33 and sync bytes. But my notes were wrong.

mikeller, 2018-01-24:
@atomiclama:

> Didn't like the way the RC data was mashed up to shorten the packet length

Is that the reduction to 4 bites resolution that you are talking about, or the fact that values that are outside of the [1000, 2000] range are encoded with less resolution? In my opinion, both of these are good approaches to maximise the bandwidth that is available for important data (i.e. the main control channels).

atomiclama, 2018-01-24:
Oh I can't remember the details ;-) it was a while back.

Yes agreed they are good methods to reduce the bandwidth.
I just wanted it simple to start with.

geofrancis, 2018-01-24:
there is a bigger issue this would fix other than more cpu/memory and that is the eprom corruption issues that effects most openlrs hardware since most of it runs the 328 @ 3.3v causing it to corupt the eprom. if it browns out or is power cycled fast,

mikeller, 2018-01-24:
To get back to the original topic of this issue:
I think porting to a different architecture is a worthwhile endeavour, and STM32 is a good candidate. BUT considering that 99% of the existing hardware, and pretty much all of the readily available new hardware currently is Atmel, we should be doing it by *adding* support for STM32, while keeping the existing hardware fully supported for the foreseeable future (even for new features).

geofrancis, 2018-01-24:
there is already a stm32 port for openlrsng but its very old and im not sure what condition its in, there was a 32bit module that dtfuhf was working on but it never really went anywhere, but it could be a good place to start.

https://github.com/openLRSng/openLRSng32/commits/v3.2

mlyle, 2018-01-24:
If one moved to STM32, it might also be worth moving away from RFM22 to some LoRa modules-- that are a couple decibels more sensitive for GFSK/FSK and also support LoRa modes.  There's a lot of SX127x-based modules e.g. RA-01.

geofrancis, 2018-01-24:
I would love to ditch rfm22/32bp modules, I cant count how many have failed over the years. I was looking at QLRS but because he is using the integrated mcu its very memory limited so he can only do basic telemetry.

csurf, 2018-01-24:
similar discussion going on here... #161

perhaps we need another thread that just discusses RF modules

csurf, 2018-01-24:
RF module upgrade discussion here... #168

atomiclama, 2018-01-25:
> we should be doing it by adding support for STM32, while keeping the existing hardware fully supported for the foreseeable future (even for new features).

A decision for the project owners.
But there comes a time where maintaining compatibility for old HW will hold the project back. Sometimes a clean break is required to give a project a kick.

mikeller, 2018-01-25:
> But there comes a time where maintaining compatibility for old HW will hold the project back. Sometimes a clean break is required to give a project a kick.

@atomiclama: From the discussions that were going on over the last few days I did not get the impression that there were a lot of enhancements / new features proposed that would go beyond what the existing hardware is capable of doing - potentially we'd have to look into doing different firmware 'flavours' to support different protocols, but that does not seem to be a prohibitive restriction to me, since most users will not have the requirement to switch between different protocols once the hardware has been wired up.
Yes, the point where Atmel MCUs are holding up progress and have to be ditched might come at some point in the future. But until then, putting effort into not shutting the door on users with existing hardware is worth extra effort in my opinion. Experience with the axing of STM32F1 support in Betaflight seems to prove this - users tend to be attached to hardware that is part of their builds, and resent being told they have to go and replace it to get access to new features.

atomiclama, 2018-01-25:
@mikeller

> But until then, putting effort into not shutting the door on users with existing hardware is worth extra effort in my opinion.

That's great if the devs are willing to put the effort in. I don't know how you manage to do the work you are doing. Hats off to you. I can't even keep 1 quad in a flying state ;-)

mikeller, 2018-01-25:
@atomiclama: If resourcing is so much of a problem that there is only a choice between moving to an entirely new platform, or supporting your existing users, then I think the choice should be to support your existing users.

If users are forced to replace their hardware, a lot of them will potentially jump ship and go for one of the established and readily available long range systems from TBS or FrSky...

csurf, 2018-01-25:
My opinion is that, for AVR platforms, we try to clean-up and add as many practical features as possible before finally freezing & EOL'ing development for it. Existing AVR users will still be able to use old, stable code, but no further development efforts will be dedicated to it if it means having to 'jump through hoops' in order to make new features work on older hardware, and or if it risks compromising the functional stability ( same mentality as in betaflight/iNav development, where older STM platforms slowly get phased out).

For future development with an upgraded MCU (STM or whatever it ends up being), there are lots of 'bells & whistles' features that we can probably look into adding.

here's a non-definitive list (feel free to add more to wish list):
- LCD support
- full, robust telemetry support for MAVLINK, CRSF, LTM, etc.
- native bluetooth and/or wifi for configuration & telemetry
- 'advanced' locator beacon with support for GPS, morse, and beacon (I was already working on this for the AVR)
- come up with some kind of adaptive frequency-hopping strategy, where the RX can suggest to the TX that 'bad', noisy hop channels can be exchanged/replaced with 'good', low-noise channels.
- anything else???

jonathan2018, 2018-01-26:
s martport or fport ?

mikeller, 2018-01-26:
@jonathan2018: Can do both, they are 90% identical.
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
geofrancis, 2018-01-28:
> Good point. The pain of having to deal with unidirectional / bidirectional / inverted UARTs externally should be avoided right from the get-go for new hardware.

with multiple UARTS like on a f3 board you could do a lot of things, specifically serial receiver with telemetry and you could even have a another port for a gps or telemetry converter or LEDS or VTX control,  so something in that direction might be the way to go

Timvrakas, 2018-01-28:
The TauLink hardware checks all the boxes for me. I hope to have custom SiLabs based radio done soon, which could replace the rfm22 with only small software changes. PlatformIO support is also great for STM.

On the other hand you might consider an ESP-8266 as the MCU and also a WiFi interface. Personally, WiFi always beats Bluetooth. Or if you wan't more power, the ESP32 is a faster MCU, with WiFi and Bluetooth.

atomiclama, 2018-01-29:
This module also exists at the moment and would be good to get up and running.

https://www.banggood.com/OpenPilot-OPLINK-MINI-CC3D-REVO-Universal-Transceiver-TX-RX-Module-Integrating-Remote-Controller-p-1000081.html

atomiclama, 2018-01-29:
Can I vote for any of the STM range that has the HW encryption IP built in.

mlyle, 2018-01-30:
@atomiclama -- I would vote against, because A) ST has different SKUs in part because it creates export control problems, etc, and export control can be difficult for small manufacturers and retailers to deal with, B) GCM AES is like 27 cycles/bit on STM32, so for any reasonable throughput it is going to be a small part of the system, and C) lots of the world can't use encrypted communciations.

Note that -authenticating- messages doesn't violate amateur radio regs in most of the world, and HMAC with SHA-256 is pretty cheap.

mlyle, 2018-01-30:
Note that oplink mini and the taulinkmodule are the same thing (roughly) and run the same firmware.  TLM just has integrated bluetooth + fits in a JR module slot.

atomiclama, 2018-01-30:
@mlyle Fair enough on the encryption.

As to the module. Can the TLM be bought as an assembled module? Where from?

mlyle, 2018-01-30:
@atomiclama No, there's no commercial availability of TLM.  As you point out, oplink mini is the same hardware and can be bought and stuck in a module bay, and there's design files for TLM up.  I might be willing to make a few TLM for people (or alternatively, designing a quick TLM+some widely available SX12xx module) if there's real interest in moving forward on this.

mikerc2017, 2018-02-15:
Any think about arduino M0 ? It is arm 32bit from atmel

jnb81, 2018-04-20:
considering STM32s' I think it should be carefully chosen (as well as hw layout)
https://quadmeup.com/stm32-f1-and-f3-versus-lrs-433mhz-interference-issue/

mlyle, 2018-04-20:
@jnb81 --- the oplink hardware we're talking about has been around for 5 years, with pretty good results.  It uses good bypassing and puts the RFM module on the opposite side of the board than the micro (so there's reasonable shielding from ground planes.  Also, I don't think an interferer 15-20dB over the noise floor at very close range is worth getting too worried about.

jonathan2018, 2018-06-25:
@csurf  any idea with a Atmege328bp ?

Two more 16-bit timer/counters
Two of each USART, SPI, and I2C serial instead of one of each
Ten PWM channels instead of six

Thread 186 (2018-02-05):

Alternating TX power feature. useful?

csurf, 2018-02-05:
I'm wondering if anyone is actually using the "alternating power" TX feature, where every 'nth' packet is sent at lower power. This only affects the TX up-link to the RX, and not the telemetry down-link.

I can't think of any situation where this would actually be useful, other than for testing.

I'd like to vote for removing it, but wanted to get some feedback first.

@geofrancis, @mikeller thoughts?

mlyle, 2018-02-05:
It might be useful-- it effectively halves TX power, and provides an early indication of a failing link.

csurf, 2018-02-05:
how does it reduce the tx power in half? I don't see how it would do this, as It simply transmits 1 packet out of every sequence at the next lower power level.

From looking at the code, if you have 20 or more hop channels, it will lower the power on every 7th packet. Otherwise, it'll lower the power every 5th packet. Seems a bit arbitrary...

Unless I'm missing something, it seems more like a means of simulating 'bad hop channels' or perhaps as a 'pre-failsafe' indicator that could force you to drop lower-power packets at the edge of range. I don't personally see how this could be useful, as it would distort the averaged RSSI values on the RX side and just doesn't seem practical. It also doesn't seem to be useful for range testing as you would want a continuous low-power setting for doing range tests.

geofrancis, 2018-02-05:
i thought about something like this but the opposite, rather than sending every nth packet out at a lower power, send it at a lower data rate, stock air rate is 19200, by dropping that to 9600 you double the range without effecting the power output so you would have much degraded control but still enough to fly.

csurf, 2018-02-05:
@geofrancis something like that sounds more interesting,
The problem with that is that going to a lower datarate signifies an increase in the packet interval, and reconfiguring of the RFM registers on both ends, so it might get pretty complicated trying to keep things in sync. Not sure if it's impossible though; I'd have to take a closer look.

One thing that just occurred to me that might be cool is an option to drop to a lower rate on the RX side on failsafe or packet loss after some pre-configured threshold, and then manually switching to a lower data rate on the TX side (via an RC channel or the physical switch).

This way, if you're at the edge of range, you can manually drop your TX to a lower data rate via the switch. The RX will immediately go into failsafe as it can no longer detect packets at the higher data rate, and then drop down to the lower data rate. After slow hopping for a full hop sequence, it should be able to catch a packet at the lower rate and link up with the TX again...

Bear in mind that this would be for a non-telemetry setup. With telemetry, maybe we could come up with a means of sending a 'switch data rate' command.

geofrancis, 2018-02-05:
that sounds like a much simpler way of implementing it,  you could just update the first 4 or 6 channels fast then the rest at 1hz. that way you could possibly go even lower than 4800.

geofrancis, 2018-02-05:
the undead mod of openlrs that openlrsng is based on was originally designed for maximum range at low data rates 100mw modules @ 4800 baud would get up to 8km.

geofrancis, 2018-02-05:
another interesting idea would be using a spare pin to control a voltage regulator connected to a rfm23bp module allowing you to control the power out of the module by regulating the PA.

I built a module long ago that could switch between around 350mw and 1W by adding a 6v regulator and switching between it and the stock 3.3v. The first time I tried it with the module on would reset but by using a large capacitor I could hotswitch without it glitching.

csurf, 2018-02-05:
@geofrancis, moved e-mode discussion to separate thread, #188

back to topic... I'm fairly convinced we can do away with the "alternating power on every nth packet" feature, unless there's a more compelling argument to keep it. thoughts?

mlyle, 2018-02-05:
Ah, every 7th sounds unfortunate, but if you do every-other-one that sounds good...  Approximately halves power, and provides a hint that you don't have too many decibels left until loss starts occurring.

fiveangle, 2018-02-09:
Agree that every 7th seems somewhat long between notices.  I'd expect it to be difficult to craft algo in RX to discern that from normal loss.

But ability for RX to sense signal transition from "solid" to "fringe" seems quite valuable.  Ideally "Full" and "Reduced" power could be set in configurator, then some simple logic in RX to "notice" that every other packet (or every Nth) is consistently missing all of a sudden, triggering an automatic down-weighting for reporting of link quality (to parlay onto the discussion of this at https://github.com/openLRSng/openLRSng/issues/191 and how "RSSI" is an antiquated metric that we need to ween people off of conflating with link quality).  "e-mode" would be another big down-weighting that should forcefully latch reported link qualtiy to some set maximum.

I don't mean to disjoint the discussion, but they do seem interrelated from the user-feedback perspective (telemetry, and/or reported "link quality")

mlyle, 2018-02-09:
There's already a great link quality metric in OpenLRS-- combined.  From 128..255 is RSSI + 128.  If you have lost frames in the last 15, it's the number of frames that made it through * 9.   It combines well with this mechanism.

csurf, 2018-02-12:
feature will be EOL'ed/removed. closing...

mlyle, 2018-02-12:
OK, that's too bad, because the last 15 frame receive status is used for link quality, and this provides an early detection of link failure even if RSSI is artificially high.

fiveangle, 2018-02-14:
That this mode ensures that at least one low-power packet would have been sent within the 15 packet rolling window, it seems prudent to keep the feature, no ?

I think what it really needs isn't to be EOLed, but documented (or just made a part of every mode (!) )

csurf, 2018-02-14:
thanks for the info guys.
I appreciate the feedback & concerns.

However, the more I've rolled this over, I really don't see a viable, practical application for this feature other than for testing. Here are a few of the main points why:
- other than the periodic nature of the lower-power packets, there's really no way to distinguish whether any resulting packet loss is due to the 'alternating power' feature, or to local noise that's simply causing issues with a specific hop channel(s)
- because of the way RSSI is averaged, the low-power packets would throw off the average and artificially skew the resulting RSSI value. This basically forces you into believing that your RSSI and range are lower than they potentially could be, which doesn't seem very useful (Most people would like to squeeze every bit of range & performance from their UHF setups)
- this feature only works on the TX side, and wouldn't affect the telemetry link, so it wouldn't have any useful implications in a 2-way link scenario, other than to slighty handicap your uplink range.
- unless you're using an OSD or telemetry, it's completely useless for 1-way / non-telemetry links
- also pretty much useless with LOS flying, unless you've got telemetry setup to send data to your radio or some other means (in which case, you can just setup a 'low RSSI' alert on your radio)
- there are probably better ways to assess edge-of-range rather than purposely debilitating the up-link: RSSI via telemetry, low RSSI alerts (we could probably implement via TX buzzer), more or better link-state variables that can be sent to an OSD (this somewhat relates to #191), etc.

fiveangle, 2018-02-18:
Some responses to your bullets...

There's no need to distinguish between naturally lost packets and purposefully missing packets, as the timing of the purposely missing packets are distributed evenly across all the hop channels through careful timing selection (hence the one every 15th).
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
mikeller, 2018-02-18:
@csurf: I don't think anybody is trying to attack you, or your efforts. On the contrary, I would think that most of the people following openLRSng on GitHub are very thankful for the time and effort you are putting in.

There are a couple of lively discussions about suggestions, and I think this is a good thing: Getting input from very varied angles is one of the strengths that open source projects such as this have. The downside of this is that often it will require a lot of discussion to work out an agreement between all the different angles. The delayed nature and slow turnaround for discussions on GitHub does not help there.

The point I was trying to make above was not about you, or your efforts, it was just that if there are people who care about the alternating power feature, and think it might have a use, it should be kept around as long as it can.

Re your point about the flash space shortage. I think in the case of MavLink (and other potential protocols like CRSF), getting them all at once into flash will not be an option, and we should consider building different firmware images for different protocols. Once the source has been refactored, this should not be a major problem.

fiveangle, 2018-02-19:
@csurf - I was exclaiming my own initial subconscious bias, not yours.  I think @mikeller might have took my statement as an indictment of you but I did not mean it that way so I take responsibility for that.

While you certainly could "be a d*ck" you certainly don't seem the type 😄

The "_remove features if they can't fit_" model used by BF I feel just won't be possible due to the severely limited PROGMEM resources of the AVR Harvard arch, and it doesn't need to be possible: with all of your valuable work to clean up the code, segmenting the universe into a few feature-specific build bundles shouldn't be hard at all !

mlyle, 2018-02-19:
Please note with all of these changes that interoperability is important--
both with old receiver firmwares and other implementations.

We have a very limited flag space in binding conf and it needs to be used
carefully-- while feature-specific builds or larger parts can ameliorate
pure flash or ram limitations they do not address the variety of things
that can go over the air which must be kept limited for interoperability
and keeping a dense encoding.

Also please note that I have forked and have a complete Rx impl on stm32
f1/f3/f4 and a functional but not complete tx implementation.  I am further
cleaning them up but they are already interoperable and a cleaner code base
than the present openlrsng.  I am on a cruise for the next week but will be
then returning to finish things up and publish.

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

mikeller, 2018-02-19:
@mlyle: How do you want to proceed with the STM32 implementation? Should this be added to a new repository, or will it be suitable to be kept in a combined repository with the old AtMega stuff?

Also, happy cruising! :motor_boat:

Kelly-Foster, 2018-02-20:
@mlyle - - outstanding work on the STM32 development!

mlyle, 2018-02-21:
Thanks :)

It is a very different impl that should be in its own tree eventually.
Right now it is in the dRonin tree which is an openpilot derivative.

https://github.com/mlyle/dronin/blob/mpl-raydio/flight/PiOS/Common/pios_openlrs.c

Is the current pushed status.  It is pretty easy to understand code but I'm
planning further cleanup.  The transmit path needs completion and a non-gcs
config interface is necessary.

On Mon, Feb 19, 2018, 6:57 PM Michael Keller <notifications@github.com>
wrote:

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

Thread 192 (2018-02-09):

PWM control of RFM23bp power amplifier

geofrancis, 2018-02-09:
Many years ago I built a module that could hotswitch between 3.3v and 5v going to the PA allowing me some control over the power output of the module, it basically involved a switch going between the stock 3.3v pad and a separate 6v regulator with some diodes and large capacitor to smooth out the transition. The first time I tried switching the module without the capacitor it would just reset but adding the capacitor slowed the transition enough that it would switch reliably.

now that got me thinking, there are plenty of spare pins on the Tx module that could be used to run a basic pwm voltage controller using a regulator, transistor, capacitor and some resistors so it could modulate its own output directly by changing the voltage to the PA without my crude switching device or reducing the power into the amplifier like the software currently does.

csurf, 2018-02-09:
This is more of a hardware design issue, but we could definitely add code to support it. Someone would need to breadboard it and test it out though.

There might be some pretty cool things that can be done with this.

One idea might be to gradually ramp up/down of the power output depending on what the RX's RSSI value (received over telemetry). i.e., we could try to keep the RSSI at a decent level, and adjust the transmit power up & down as necessary just enough to keep the link solid while also keeping transmit power at a minimum.

Another cool thing might be to monitor the RF module's temperature via the built-in temp sensor, and then kill the power if it starts getting too hot (we should already be monitoring it for emergency/alert purposes, but it never got done).

csurf, 2018-02-12:
@geofrancis
would you be willing & able to mock this up hardware-wise?

goahead0, 2018-03-08:
According to hoperfs datasheet the rfm23bps PA is theoretically capable of power levels of +1 to +30 dBm. Practically there seem to be severe limitations on finely adjusting the tx power. There are just three bits in reg 6d which deals with the PA.

The data sheet is unclear, they talk about setting the power level in 3dB steps, but the table provided only lists +28/29/30dBm. It looks like the reduced energy efficiency prompted hoperf to restrict the usable power range.

A first step requiring no hardware modifications would be to set the PA power in the limited range possible according to the temperature value delivered by the internal sensor.

The remaining 5 bits of register 6d are unexplained in the data sheet and it looks like they are also not used in openLRSng. The module already has the hardware to control the power level. Before adding hw-pwm to control the module supply voltage externally, it might be good to make sure it really is necessary.

I'll ask hoperf if they can clarify the issue if no one already has done so.

atomiclama, 2018-03-08:
I have one of these modules on the way and was planning on doing some current measurements at various register settings and VCC levels. I'll post up any measurements I get.

goahead0, 2018-03-09:
According to hoperf's technical support the rfm23bp is based on a si4431 + external PA. The power settings in register 6d allow to set the power for the si4431 in 3dBm steps from -8dBm to +13dBm. The PA adds roughly 20dBm to this (depending on supply voltage). So the output power can roughly be set from a minimum of about 12dBm up to 33dBm for a supply voltage of 5V in an ideal situation.

The graphics below illustrates the PA power and current consumption for a voltage range of 3.6V - 9V depending on the input power:

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

artemen, 2018-03-19:
I've recently decided to do the [Narpat's](https://www.rcgroups.com/forums/showpost.php?p=33899703&postcount=3691) mod and power PA separately from the Si4331, as expected at 9v we do get around 2w of output from the old rfm23bp, also if done properly heat is not excessive and PA runs for more than 24hrs without frying. this was demonstrated by Narpat a year ago. What's not expected is that even with about than 33dbm output, packet loss rate didn't change much, this made me think that either RX or TX or both do not get locked properly onto the exact frequency. If so, would this be hardware fault or code fault?

mikerc2017, 2018-03-19:
@artemen

after you mod 9v for PA , range better ? i try mod 6v for Modul on TX , but seem result not change

artemen, 2018-03-19:
Range is marginally better, i would say i've notced ine spot where I woild loose rc link almost 2km away at about 2-3 meters anove ground it was behind trees and a small building, i have solid control there now, though loose about half the packets.  Haven't tested in long range yet.

mikerc2017, 2018-03-19:
seem still not yet perfect, if RX have a LNA  ,maybe range will better instead mod Highvolt for modul ?

goahead0, 2018-03-23:
The module already contains an LNA + programmable amplifier with automatic gain control for the rx. Lora's higher sensitivity comes at the price of a much reduced data rate. I would concentrate on good antennas.

2km away, 2-3m above ground and behind multiple obstacles you can't seriously expect a much better result.

artemen, 2018-03-23:
@goahead0
 how about 4km and 10 meters above ground on a multie?  ;)

goahead0, 2018-03-23:
Too many unknown factors involved for me to compare and not to speculate.

artemen, 2018-03-23:
@goahead0
can't agree more with you, so many videos of DL flying 7-8 km only meters above the ground, but never mention that ground station is elevated or if they are flying uphill.

 4170meters out 12meters above takeoff point about 7-8 meters above ground on a flat as pancake terrain with some trees but mostly grass fields in a suburban area. nagoya on dtfuhf delux TXv1 and diy diploes on a diy diversity running broversity code.

mikerc2017, 2018-03-24:
distance  2m  above ground. i  only can move to 500m .All use dipole anten. modul 1w .
@artemen   i real want to see your video.

artemen, 2018-03-24:
@mikerc2017
a year ago new place not exactly two meters but low enough to be behind multiple trees ans a few houses:
https://www.youtube.com/watch?v=9lWgp0LnbVs

one of the first flights of the season, the end of this February
https://youtu.be/iHCLbrwrBTI?t=380 at this frame abpout 9-10meters above takeoff point,  3.9-4km out. watch from the begining to get the scale, video ends at 4.4km

mikerc2017, 2018-03-25:
Thanks artemen

and everyone : i find a modul 500mw with support  **LNA**  , i will order and test  and report

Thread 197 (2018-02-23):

Atmega32u4 Rx possible?

ameeuw, 2018-02-23:
Hey everybody - really nice to see some activity within this repo again. I am getting my old OrangeRx gear up again and now tried to also build my own light-weight receiver. So far I have tried to build one with a 3.3v 8MHz arduino mini pro but was rather unsuccessful due to the timing issues with the 8MHz running chip...

Now I stumbled across the "beetle" board - a quite small and nice square board with a atmega32u4, broken out SPI and two onboard LEDs. The version I linked below also features a 3.3v regulator. I guess one could even saw off the USB-connector if in need for a really tiny receiver.

[AliExpress Link](https://www.aliexpress.com/item/Beetle-Virtual-Keyboard-BadUSB-Pro-Micro-ATMEGA32U4-Module-Mini-Development-Expansion-Board-For-Arduino-Leonardo-R3/32847715254.html)

My question about this is: How big is the effort to enable receiver code for the 32u4? The DTFUHF/HawkEye deluxe TX (TX_BOARD_TYPE 6) also uses the 32u4 - is this just a matter of pin redefinition and adjusting the switching routines?

mikeller, 2018-02-24:
@ameeuw: That's a neat board. I think it shouldn't be too hard, and giving it a go can't hurt. Look into `openLRSng/hardware.h` to find the pin definitions.

ameeuw, 2018-02-25:
I looked into it a little and made a testing board using an Arduino Pro Micro. So far I have been getting the TX-code to compile and work an RF22b.
I tried to just copy over the pin definitions like I did for my own diy receiver but it seems like none of the switching and timing logic of the receiver in `openLRSng/RX.h` can be directly taken over to the leonardo.
Is somebody firm with atmega32u4 hardware and its functions? I fear I do not have the knowledge to go over the RX code and adapt it.

ameeuw, 2018-02-28:
I actually stumbled across a maybe even easier solution...
[OpenLog (github link)](https://github.com/sparkfun/OpenLog) is an open source datalogger and is very cheaply available:

[AliExpress Link](https://www.aliexpress.com/item/1pcs-Openlog-Serial-Data-Logger-Open-Source-Data-Recorder-ATmega328-Support-Micro-SD-for-arduino/32838430172.html)

It is a board with an ATmega328 that runs on 3.3v with 16MHz - has SPI with CS and another pin (for nIRQ) broken out to the SD-card-holder. I guess if you desolder the sdcard this would be rather suitable.

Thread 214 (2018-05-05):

PPM output not compatible with iNAV

padcom, 2018-05-05:
I have tested a number of different receivers outputting PPM with iNAV/Betaflight and Omnibus F4 v2 board:

- https://www.banggood.com/Tiny-Frsky-8CH-Receiver-Compatible-With-FRSKY-X9D-Plus-DJT-DFT-DHT-For-QX90-DIY-Micro-Quadcopter-p-1079963.html
- https://www.banggood.com/DIY-FRSKY-8CH-Receiver-RX-PPM-Output-For-X9DPLUS-XJT-DJT-DFT-DHT-p-987247.html
- https://hobbyking.com/en_us/dsm2-6ch-with-case-and-ce-fcc-rcm.html

In all cases PPM output gets properly through to iNAV (tested with 12 channels) without any hardware modifications.

OrangeRX LRS receiver with OpenLRSng is different and does not get through at all.

I know there is a jumper that can be removed to get the OrangeRX LRS receiver to accept PPM from OrangeRX LRS receiver but can't seem to find the reason why the other PPM receivers do work without that mod. After all PPM is generated in software and does not need any hardware inverter. Am I correct?

Is it possible to get the LRS receiver to work without changing the jumper?

geofrancis, 2018-05-05:
you need to limit ppm channels to 8 in the rx configuration page.

padcom, 2018-05-05:
I've done that and I have disabled injection of RSSI on channel 12 (just to make sure there aren't any additional settings that might somehow affect it). iNAV still doesn't see the PPM signal from the RX.

It is worth mentioning that the 8 channel limit is not needed when the jumper is off - too bad it needs to be soldered :(

padcom, 2018-05-05:
I have tested it again on 2 other OrangeRX LRS receivers and the situation is all the same. I wonder if this isn't some kind of design flaw on the receiver. But if that would be the case then why removing the jumper suddenly makes the PPM signal recognized by iNAV?

mikeller, 2018-05-05:
I know this isn't an answer to your question, but why aren't you using SUMD if you want to control iNav over openLRSng? This will give you 16 channels without any issues.

padcom, 2018-05-05:
Quite frankly I am as this is the only viable option at this time. I just can't let go of the fact that all other receivers do work with PPM. The number of issues flying around on both OLRS and Betaflight/Cleanflight/iNAV is huge and they all are being answered with "it just doesn't work; remove the jumper".

The problem with removing the jumper is two-fold: a) it hinders the ability to use SBUS all together and b) it requires intervention with a soldering iron which voids the warranty of the board which is bad.

I think I would let it all go if all the other receivers wouldn't work too but they are working fine.

I have one more test to do with another OLRSng-powered receiver (Wolfbox) but that needs to arrive and it will take some time. That way I'll be able to determine if it is the hardware that is causing PPM not to work or if this is indeed a software issue.

mikeller, 2018-05-06:
Fair enough. I don't know how much sense it makes to put more time / effort into this. Considering that the RX and the flight controller are both digital systems, using a digital protocol like SUMD to transfer information seems to be much more appropriate than using an analogue protocol, and putting up with limited options and inaccuracies.

padcom, 2018-05-06:
There is one more reason to pursue the issue: To connect the RX using SUMD you need a special cable that connects to the non-inverted UART1 using 3 pin JST SH connector instead of a regular servo wire. That connector is neither easy to come by nor long enough to mount the receiver on the wing without additional soldering. Also on the OrangeRX LRS receiver there is no direct connector available and the cable needs to be split between power line and separate UART port which is on the other end of the receiver. In both cases it makes for a far less durable connection than using a simple servo wire with PPM.

Unless there is a 3rd option (PWM doesn't count) I think it is really worth the effort to get to the bottom of it.

padcom, 2018-05-06:
I think I should have started the thread with the information that I am using the Omnibus F4 v2 on a fixed wing airplane rather than a multirotor where connections are not long and the individual components can be mounted next to each other.

geofrancis, 2018-05-06:
your setup should work, have you tested the ppm out with something else?

padcom, 2018-05-07:
Only with other receivers and the same Omnibus F4 v2 board with iNAV (see the first post). And that works. The only combo that doesn't work at the moment is OpenLRS with iNAV.

padcom, 2018-05-07:
I have good news (well, sort of...)

I have successfully tested iNAV with an OpenLRS receiver (Wolfbox). All the settings are the same as with the OrangeRX LRS receiver but this one just works.

Does anyone has any idea what is so different between the 2 receivers?

padcom, 2018-05-07:
Or at least what should I check to figure out the difference? Any suggestions are very welcome!

padcom, 2018-05-07:
Well, I have full success. Even though it requires intervention with the soldering iron I am happy to report that the problem is with the receiver itself (OrangeRX LRS RX) and NOT with iNAV or the OMNIBUS F4 v2.

Long story short on the ORX LRS RX between pins and the MCU there are 1k resistors. On Wolfbox RX there are no resistors. Once the one on channel 6 (PWM5) is bridged effectively removing that resistor the PPM signal goes through properly to the flight controller!

I presume one could replace that 1k resister with some smaller value to limit the current but for now this will do fine.

Maybe it'd make sense to put this information somewhere on the wiki?

For now I am closing this issue.

timsical, 2018-06-09:
Padcom! Please please could you explain how you solved this? I’m having the exact same issue, and it’s been driving a little nuts! I’m no engineer, so if you could give it in layman’s terms that would be awesome!

Thanks for any help!

Closed 2018-05-07.

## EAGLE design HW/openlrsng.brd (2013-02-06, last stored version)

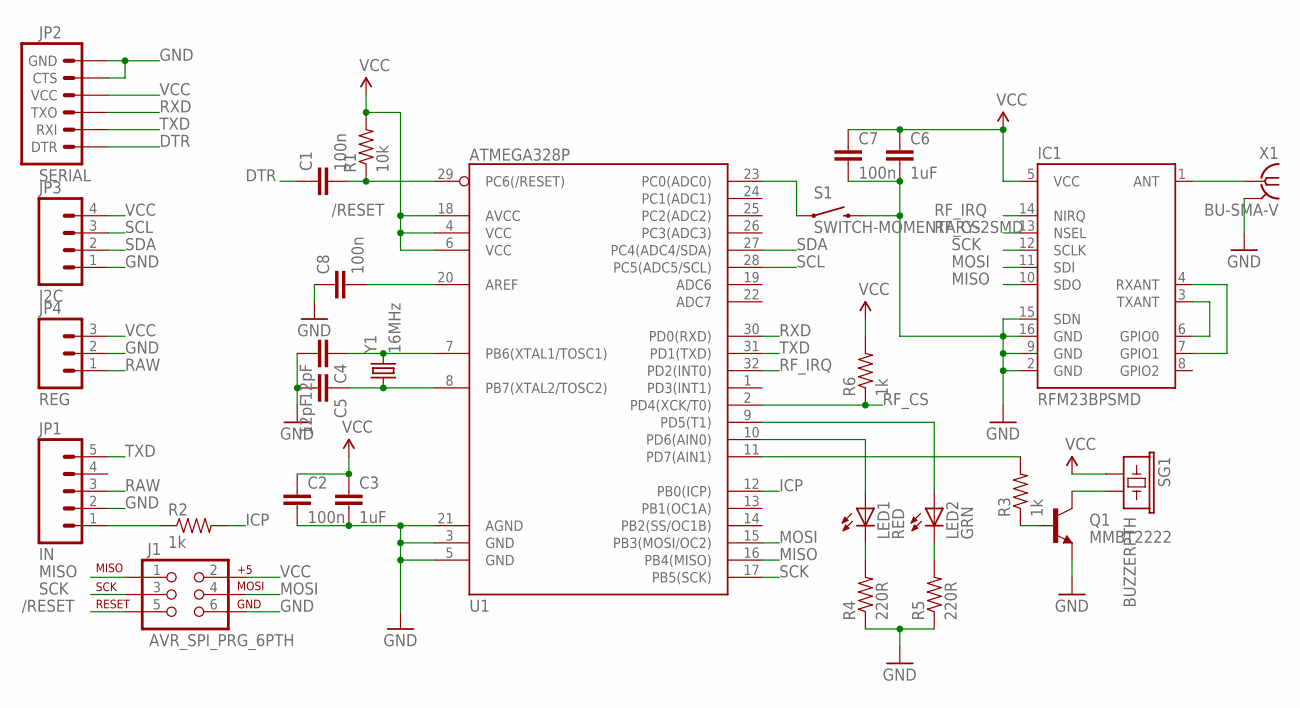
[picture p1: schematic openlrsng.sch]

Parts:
C1, C2, C7, C8: 100n; 0805
C3, C6: 1uF; 0805
C4, C5: 12pF; 0805
IC1: RFM23BPSMD; RFM23BP-S2
J1: AVR_SPI_PRG_6PTH; 2X3
JP1: IN; 1X05
JP2: SERIAL; 1X06
JP3: I2C; 1X04
JP4: REG; 1X03
LED1: RED; LED3MM
LED2: GRN; LED3MM
Q1: MMBT2222; SOT23-3
R1: 10k; 0402-RES
R2, R3, R6: 1k; 0402-RES
R4, R5: 220R; 0402-RES
S1: SWITCH-MOMENTARY-2SMD; TACTILE_SWITCH_SMD
SG1: BUZZERPTH; BUZZER-12MM
U1: ATMEGA328P; TQFP32-08
X1: BU-SMA-V
Y1: 16MHz; CRYSTAL-SMD-5X3

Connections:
/RESET: C1.2, J1.5, R1.1, U1.29 (PC6(/RESET))
DTR: C1.1, JP2.1 (DTR)
GND: C2.2, C3.2, C4.2, C5.2, C6.2, C7.2, C8.1, IC1.2 (GND), IC1.9 (GND), IC1.15 (SDN), IC1.16 (GND), J1.6, JP1.2, JP2.5 (CTS), JP2.6 (GND), JP3.1, JP4.2, Q1.2 (E), R4.1, R5.1, S1.3 (2), U1.3 (GND), U1.5 (GND), U1.21 (AGND), X1.2, X1.3 (2), X1.4 (2), X1.5 (2)
ICP: R2.2, U1.12 (PB0(ICP))
MISO: IC1.10 (SDO), J1.1, U1.16 (PB4(MISO))
MOSI: IC1.11 (SDI), J1.4, U1.15 (PB3(MOSI/OC2))
unnamed: IC1.3 (TXANT), IC1.6 (GPIO0)
unnamed: IC1.4 (RXANT), IC1.7 (GPIO1)
unnamed: JP1.1, R2.1
unnamed: R3.2, U1.11 (PD7(AIN1))
unnamed: Q1.1 (B), R3.1
unnamed: Q1.3 (C), SG1.- (2)
unnamed: LED1.A, U1.10 (PD6(AIN0))
unnamed: LED2.A, U1.9 (PD5(T1))
unnamed: LED1.K (C), R4.2
unnamed: LED2.K (C), R5.2
unnamed: C4.1, U1.7 (PB6(XTAL1/TOSC1)), Y1.3 (2)
unnamed: C5.1, U1.8 (PB7(XTAL2/TOSC2)), Y1.1
unnamed: IC1.1 (ANT), X1.1
unnamed: C8.2, U1.20 (AREF)
unnamed: S1.1, U1.23 (PC0(ADC0))
RAW: JP1.3, JP4.1
RF_CS: IC1.13 (NSEL), R6.1, U1.2 (PD4(XCK/T0))
RF_IRQ: IC1.14 (NIRQ), U1.32 (PD2(INT0))
RXD: JP2.3 (TXO), U1.30 (PD0(RXD))
SCK: IC1.12 (SCLK), J1.3, U1.17 (PB5(SCK))
SCL: JP3.3, U1.28 (PC5(ADC5/SCL))
SDA: JP3.2, U1.27 (PC4(ADC4/SDA))
TXD: JP1.5, JP2.2 (RXI), U1.31 (PD1(TXD))
VCC: C2.1, C3.1, C6.1, C7.1, IC1.5 (VCC), J1.2, JP2.4 (VCC), JP3.4, JP4.3, R1.2, R6.2, SG1.+ (1), U1.4 (VCC), U1.6 (VCC), U1.18 (AVCC)

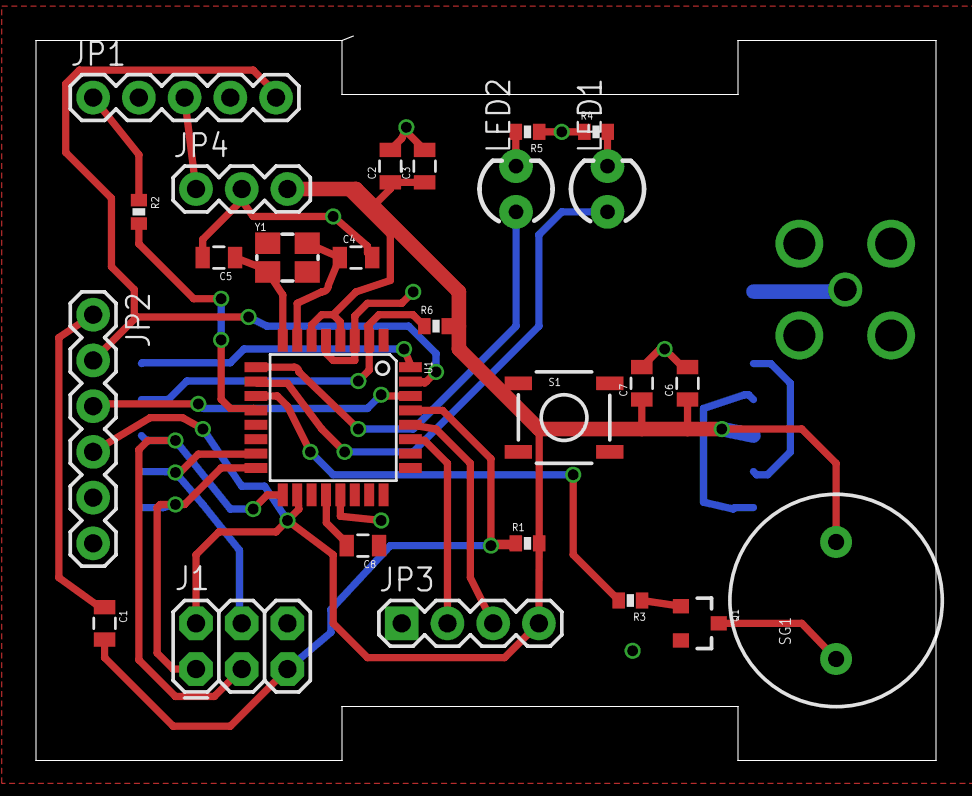
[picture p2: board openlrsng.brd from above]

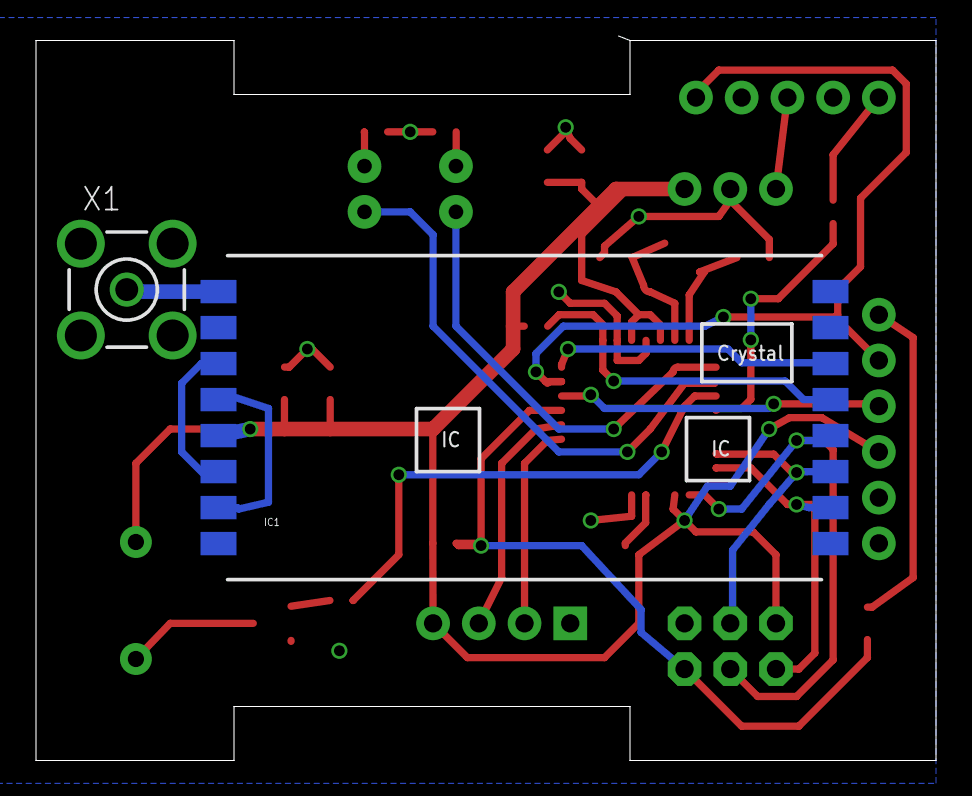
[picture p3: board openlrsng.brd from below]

Board: 2 copper layers, 50.0 x 40.0 mm, 28 parts (2 on the bottom side), 30 nets.

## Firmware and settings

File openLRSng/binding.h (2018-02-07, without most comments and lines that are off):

#define _BINDING_H_
#define DEFAULT_RF_POWER 7
#define DEFAULT_CHANNEL_SPACING 5 // 50kHz
#define DEFAULT_HOPLIST 22,10,19,34,49,41
#define DEFAULT_RF_MAGIC 0xDEADFEED
#define DEFAULT_DATARATE 2
#define DEFAULT_BAUDRATE 115200
#define SW_POWER            0x04 // enable powertoggle via switch (JR dTX)
#define ALT_POWER           0x08
#define MUTE_TX             0x10 // do not beep on telemetry loss
#define MICROPPM            0x20
#define INVERTED_PPMIN      0x40
#define WATCHDOG_USED       0x80 // read only flag, only sent to configurator
#define PPM_MAX_8CH         0x01
#define ALWAYS_BIND         0x02
#define SLAVE_MODE          0x04
#define IMMEDIATE_OUTPUT    0x08
#define STATIC_BEACON       0x10
#define INVERTED_PPMOUT      0x40
#define WATCHDOG_USED       0x80 // read only flag, only sent to configurator
#define TELEMETRY_OFF       0x00
#define TELEMETRY_PASSTHRU  0x08
#define TELEMETRY_FRSKY     0x10 // covers smartport if used with &
#define TELEMETRY_SMARTPORT 0x18
#define TELEMETRY_MASK      0x18
#define CHANNELS_4_4        0x01
#define CHANNELS_8          0x02
#define CHANNELS_8_4        0x03
#define CHANNELS_12         0x04
#define CHANNELS_12_4       0x05
#define CHANNELS_16         0x06
#define DIVERSITY_ENABLED   0x80
#define DEFAULT_FLAGS       (CHANNELS_8 | TELEMETRY_PASSTHRU)
typedef enum {
    SERIAL_MODE_NONE = 0,
    SERIAL_MODE_SPEKTRUM1024,
    SERIAL_MODE_SPEKTRUM2048,
    SERIAL_MODE_SBUS,
    SERIAL_MODE_SUMD,
    SERIAL_MODE_MULTI,
    SERIAL_MODE_MAX = SERIAL_MODE_MULTI
} serialMode_e;
#define MULTI_OPERATION_TIMEOUT_MS 5000
#define EU_PMR_CH(x) (445993750L + 12500L * (x)) // valid for ch1-ch16 (Jan 2016  ECC update)
#define US_FRS_CH(x) (462537500L + 25000L * (x)) // valid for ch1-ch7
#define DEFAULT_BEACON_FREQUENCY 0 // disable beacon
#define DEFAULT_BEACON_DEADTIME 30 // time to wait until go into beacon mode (30s)
#define DEFAULT_BEACON_INTERVAL 10 // interval between beacon transmits (10s)
#define MIN_DEADTIME 0
#define MAX_DEADTIME 255
#define MIN_INTERVAL 1
#define MAX_INTERVAL 255
#define BINDING_POWER     0x06 // not lowest since may result fail with RFM23BP
#define TELEMETRY_PACKETSIZE 9
#define MAX_PACKETSIZE 21
#define BIND_MAGIC (0xDEC1BE15 + (OPENLRSNG_VERSION & 0xfff0))
#define BINDING_VERSION ((OPENLRSNG_VERSION & 0x0ff0)>>4)
static uint8_t default_hop_list[] = {DEFAULT_HOPLIST};
#if (RFMTYPE == 868)
#  define MIN_RFM_FREQUENCY 848000000
#  define MAX_RFM_FREQUENCY 888000000
#  define DEFAULT_CARRIER_FREQUENCY 868000000  // Hz  (ch 0)
#  define BINDING_FREQUENCY 868000000 // Hz
#elif (RFMTYPE == 915)
#  define MIN_RFM_FREQUENCY 895000000
#  define MAX_RFM_FREQUENCY 935000000
#  define DEFAULT_CARRIER_FREQUENCY 915000000  // Hz  (ch 0)
#  define BINDING_FREQUENCY 915000000 // Hz
#else
#  define MIN_RFM_FREQUENCY 413000000
#  define MAX_RFM_FREQUENCY 463000000
#  define DEFAULT_CARRIER_FREQUENCY 435000000  // Hz  (ch 0)
#  define BINDING_FREQUENCY 435000000 // Hz
#endif
#define MAXHOPS      24
#define PPM_CHANNELS 16
uint8_t activeProfile = 0;
uint8_t defaultProfile = 0;
struct tx_config {
  uint8_t  rfm_type;
  uint32_t max_frequency;
  uint32_t console_baud_rate;
  uint32_t flags;
  uint8_t  chmap[16];
} tx_config;
#define TX_CONFIG_GETMINCH() (tx_config.flags >> 28)
#define TX_CONFIG_SETMINCH(x) (tx_config.flags = (tx_config.flags & 0x0fffffff) | (((uint32_t)(x) & 0x0f) << 28))
struct RX_config {
  uint8_t  rx_type; // RX type fillled in by RX, do not change
  uint8_t  pinMapping[13];
  uint8_t  flags;
  uint8_t  RSSIpwm; //0-15 inject composite, 16-31 inject quality, 32-47 inject RSSI, 48-63 inject quality & RSSI on two separate channels
  uint32_t beacon_frequency;
  uint8_t  beacon_deadtime;
  uint8_t  beacon_interval;
  uint16_t minsync;
  uint8_t  failsafeDelay;
  uint8_t  ppmStopDelay;
  uint8_t  pwmStopDelay;
} rx_config;
struct bind_data {
  uint8_t version;
  uint32_t serial_baudrate;
  uint32_t rf_frequency;
  uint32_t rf_magic;
  uint8_t rf_power;
  uint8_t rf_channel_spacing;
  uint8_t hopchannel[MAXHOPS];
  uint8_t modem_params;
  uint8_t flags;
} bind_data;
struct rfm22_modem_regs {
  uint32_t bps;
  uint8_t  r_1c, r_1d, r_1e, r_20, r_21, r_22, r_23, r_24, r_25, r_2a, r_6e, r_6f, r_70, r_71, r_72;
} modem_params[] = {
  { 4800, 0x1a, 0x40, 0x0a, 0xa1, 0x20, 0x4e, 0xa5, 0x00, 0x1b, 0x1e, 0x27, 0x52, 0x2c, 0x23, 0x30 }, // 50000 0x00
  { 9600, 0x05, 0x40, 0x0a, 0xa1, 0x20, 0x4e, 0xa5, 0x00, 0x20, 0x24, 0x4e, 0xa5, 0x2c, 0x23, 0x30 }, // 25000 0x00
  { 19200, 0x06, 0x40, 0x0a, 0xd0, 0x00, 0x9d, 0x49, 0x00, 0x7b, 0x28, 0x9d, 0x49, 0x2c, 0x23, 0x30 }, // 25000 0x01
  { 57600, 0x05, 0x40, 0x0a, 0x45, 0x01, 0xd7, 0xdc, 0x03, 0xb8, 0x1e, 0x0e, 0xbf, 0x00, 0x23, 0x2e },
  { 125000, 0x8a, 0x40, 0x0a, 0x60, 0x01, 0x55, 0x55, 0x02, 0xad, 0x1e, 0x20, 0x00, 0x00, 0x23, 0xc8 },
};
#define DATARATE_COUNT (sizeof(modem_params) / sizeof(modem_params[0]))
struct rfm22_modem_regs bind_params =
{ 9600, 0x05, 0x40, 0x0a, 0xa1, 0x20, 0x4e, 0xa5, 0x00, 0x20, 0x24, 0x4e, 0xa5, 0x2c, 0x23, 0x30 };
void fatalBlink(uint8_t blinks);
#include <avr/eeprom.h>
void myEEPROMwrite(int16_t addr, uint8_t data)
{
  uint8_t retries = 5;
  while ((--retries) && (data != eeprom_read_byte((uint8_t *)addr))) {
    eeprom_write_byte((uint8_t *)addr, data);
  }
  if (!retries) {
    fatalBlink(2);
  }
}
static uint16_t CRC16_value;
inline void CRC16_reset()
{
  CRC16_value = 0;
}
void CRC16_add(uint8_t c) // CCITT polynome
{
  uint8_t i;
  CRC16_value ^= (uint16_t)c << 8;
  for (i = 0; i < 8; i++) {
    if (CRC16_value & 0x8000) {
      CRC16_value = (CRC16_value << 1) ^ 0x1021;
    } else {
      CRC16_value = (CRC16_value << 1);
    }
  }
}
#if (COMPILE_TX != 1)
extern uint16_t failsafePPM[PPM_CHANNELS];
#endif
#define EEPROM_SIZE 1024 // EEPROM is 1k on 328p and 32u4
#define ROUNDUP(x) (((x)+15)&0xfff0)
#define MIN256(x)  (((x)<256)?256:(x))
#if (COMPILE_TX == 1)
#define EEPROM_DATASIZE MIN256(ROUNDUP((sizeof(tx_config) + sizeof(bind_data) + 4) * 4 + 3))
#else
#define EEPROM_DATASIZE MIN256(ROUNDUP(sizeof(rx_config) + sizeof(bind_data) + sizeof(failsafePPM) + 6))
#endif
bool accessEEPROM(uint8_t dataType, bool write)
{
  void *dataAddress = NULL;
  uint16_t dataSize = 0;
  uint16_t addressNeedle = 0;
  uint16_t addressBase = 0;
  uint16_t CRC = 0;
  do {
start:
#if (COMPILE_TX == 1)
    if (dataType == 0) {
      dataAddress = &tx_config;
      dataSize = sizeof(tx_config);
      addressNeedle = (sizeof(tx_config) + sizeof(bind_data) + 4) * activeProfile;
    } else if (dataType == 1) {
      dataAddress = &bind_data;
      dataSize = sizeof(bind_data);
      addressNeedle = sizeof(tx_config) + 2;
      addressNeedle += (sizeof(tx_config) + sizeof(bind_data) + 4) * activeProfile;
    } else if (dataType == 2) {
      dataAddress = &defaultProfile;
      dataSize = 1;
      addressNeedle = (sizeof(tx_config) + sizeof(bind_data) + 4) * 4; // defaultProfile is stored behind all 4 profiles
    }
#else
    if (dataType == 0) {
      dataAddress = &rx_config;
      dataSize = sizeof(rx_config);
      addressNeedle = 0;
    } else if (dataType == 1) {
      dataAddress = &bind_data;
      dataSize = sizeof(bind_data);
      addressNeedle = sizeof(rx_config) + 2;
    } else if (dataType == 2) {
      dataAddress = &failsafePPM;
      dataSize = sizeof(failsafePPM);
      addressNeedle = sizeof(rx_config) + sizeof(bind_data) + 4;
    }
#endif
    addressNeedle += addressBase;
    CRC16_reset();
    for (uint8_t i = 0; i < dataSize; i++, addressNeedle++) {
      if (!write) {
        *((uint8_t*)dataAddress + i) = eeprom_read_byte((uint8_t *)(addressNeedle));
      } else {
        myEEPROMwrite(addressNeedle, *((uint8_t*)dataAddress + i));
      }
      CRC16_add(*((uint8_t*)dataAddress + i));
    }
    if (!write) {
      CRC = eeprom_read_byte((uint8_t *)addressNeedle) << 8 | eeprom_read_byte((uint8_t *)(addressNeedle + 1));
      if (CRC16_value == CRC) {
        write = true;
        addressBase = 0;
        goto start;
      } else {
      }
    } else {
      myEEPROMwrite(addressNeedle++, CRC16_value >> 8);
      myEEPROMwrite(addressNeedle, CRC16_value & 0x00FF);
    }
    addressBase += EEPROM_DATASIZE;
  } while (addressBase <= (EEPROM_SIZE - EEPROM_DATASIZE));
  return (write); // success on write, failure on read
}
bool bindReadEeprom()
{
  if (accessEEPROM(1, false) && (bind_data.version == BINDING_VERSION)) {
    return true;
  }
  return false;
}
void bindWriteEeprom()
{
  accessEEPROM(1, true);
}
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

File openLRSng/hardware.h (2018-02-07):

#ifndef _HARDWARE_H_
#define _HARDWARE_H_

// Generic definitions needed always

#define RX_FLYTRON8CH 0x01
#define RX_OLRSNG4CH  0x02
#define RX_OLRSNG12CH 0x03
#define RX_DTFUHF10CH 0x04
#define RX_PTOWER     0x05
#define RX_MICRO      0x06
#define RX_FLYTRONM3  0x07
#define RX_BRORX      0x08

#define PINMAP_PPM    0x20
#define PINMAP_RSSI   0x21
#define PINMAP_SDA    0x22
#define PINMAP_SCL    0x23
#define PINMAP_RXD    0x24
#define PINMAP_TXD    0x25
#define PINMAP_ANALOG 0x26
#define PINMAP_LBEEP  0x27 // packetloss beeper
#define PINMAP_SPKTRM 0x28 // spektrum satellite output
#define PINMAP_SBUS   0x29 // SBUS output
#define PINMAP_SUMD   0x2a // SUMD output
#define PINMAP_LLIND  0x2b // LinkLoss indication (digital output)

void RFM22B_Int(void);

// Following table is used by the dialog code to
// determine possible extra functions for each output.
typedef struct pinMask {
  uint8_t B;
  uint8_t C;
  uint8_t D;
} pinMask_t;

struct rxSpecialPinMap {
  uint8_t output;
  uint8_t type;
};

#if (COMPILE_TX == 1)
#define CLI_ENABLED
#endif

//####### Board Pinouts #########

#if (BOARD_TYPE == 0) // Flytron M1 TX
#if (__AVR_ATmega328P__ != 1) || (F_CPU != 16000000)
#warning Possibly wrong board selected, select Arduino Pro/Pro Mini 5V/16MHz w/ ATMega328
#endif

#if (COMPILE_TX != 1)
#error TX module cannot be used as RX
#endif

HardwareSerial *rcSerial = &Serial;

#define PPM_IN           A5
#define RF_OUT_INDICATOR A4
#define BUZZER_ACT       9
#define BTN              10
#define PPM_Pin_Interrupt_Setup  PCMSK1 = 0x20;PCICR|=(1<<PCIE1);
#define PPM_Signal_Interrupt PCINT1_vect
#define PPM_Signal_Edge_Check ((PINC & 0x20)==0x20)

void buzzerInit()
{
  pinMode(BUZZER_ACT, OUTPUT);
  digitalWrite(BUZZER_ACT, LOW);
}

void buzzerOn(uint16_t freq)
{
  if (freq) {
    digitalWrite(BUZZER_ACT,HIGH);
  } else {
    digitalWrite(BUZZER_ACT,LOW);
  }
}

#define buzzerOff(foo) buzzerOn(0)

#define Red_LED    12
#define Green_LED  11

#define Red_LED_ON  PORTB |= _BV(4);
#define Red_LED_OFF  PORTB &= ~_BV(4);

#define Green_LED_ON   PORTB |= _BV(3);
#define Green_LED_OFF  PORTB &= ~_BV(3);


//## RFM22B Pinouts for Public Edition (M1 or Rx v1)
#define  nIRQ_1 (PIND & 0x08)==0x08 //D3
#define  nIRQ_0 (PIND & 0x08)==0x00 //D3

#define  nSEL_on PORTD |= (1<<4) //D4
#define  nSEL_off PORTD &= 0xEF //D4

#define  SCK_on PORTD |= (1<<2) //D2
#define  SCK_off PORTD &= 0xFB //D2

#define  SDI_on PORTC |= (1<<1) //C1
#define  SDI_off PORTC &= 0xFD //C1

#define  SDO_1 (PINC & 0x01) == 0x01 //C0
#define  SDO_0 (PINC & 0x01) == 0x00 //C0

#define SDO_pin A0
#define SDI_pin A1
#define SCLK_pin 2
#define IRQ_pin 3
#define nSel_pin 4

void setupSPI()
{
  pinMode(SDO_pin, INPUT);   //SDO
  pinMode(SDI_pin, OUTPUT);   //SDI
  pinMode(SCLK_pin, OUTPUT);   //SCLK
  pinMode(IRQ_pin, INPUT);   //IRQ
  pinMode(nSel_pin, OUTPUT);   //nSEL
}

#define IRQ_interrupt 1
void setupRfmInterrupt()
{
  attachInterrupt(IRQ_interrupt, RFM22B_Int, FALLING);
}

#endif

#if (BOARD_TYPE == 1) // Flytron M1 RX
#if (__AVR_ATmega328P__ != 1) || (F_CPU != 16000000)
#warning Possibly wrong board selected, select Arduino Pro/Pro Mini 5V/16MHz w/ ATMega328
#endif

#if (COMPILE_TX != 1)
#error M1 RX not verified yet
#endif

HardwareSerial *rcSerial = &Serial;

#define PPM_IN     5
#define BUZZER_ACT 7
#define BTN        8

#define Red_LED A3
#define Green_LED A2

#define Red_LED_ON  PORTC &= ~_BV(2);PORTC |= _BV(3);
#define Red_LED_OFF  PORTC &= ~_BV(2);PORTC &= ~_BV(3);

#define Green_LED_ON  PORTC &= ~_BV(3);PORTC |= _BV(2);
#define Green_LED_OFF  PORTC &= ~_BV(3);PORTC &= ~_BV(2);

#define PPM_Pin_Interrupt_Setup  PCMSK2 = 0x20;PCICR|=(1<<PCIE2);
#define PPM_Signal_Interrupt PCINT2_vect
#define PPM_Signal_Edge_Check ((PIND & 0x20)==0x20)

void buzzerInit()
{
  pinMode(BUZZER_ACT, OUTPUT);
  digitalWrite(BUZZER_ACT, LOW);
}

void buzzerOn(uint16_t freq)
{
  if (freq) {
    digitalWrite(BUZZER_ACT,HIGH);
  } else {
    digitalWrite(BUZZER_ACT,LOW);
  }
}

#define buzzerOff(foo) buzzerOn(0)

//## RFM22B Pinouts for Public Edition (M1 or Rx v1)
#define  nIRQ_1 (PIND & 0x08)==0x08 //D3
#define  nIRQ_0 (PIND & 0x08)==0x00 //D3

#define  nSEL_on PORTD |= (1<<4) //D4
#define  nSEL_off PORTD &= 0xEF //D4

#define  SCK_on PORTD |= (1<<2) //D2
#define  SCK_off PORTD &= 0xFB //D2

#define  SDI_on PORTC |= (1<<1) //C1
#define  SDI_off PORTC &= 0xFD //C1

#define  SDO_1 (PINC & 0x01) == 0x01 //C0
#define  SDO_0 (PINC & 0x01) == 0x00 //C0

#define SDO_pin A0
#define SDI_pin A1
#define SCLK_pin 2
#define IRQ_pin 3
#define nSel_pin 4

void setupSPI()
{
  pinMode(SDO_pin, INPUT);   //SDO
  pinMode(SDI_pin, OUTPUT);   //SDI
  pinMode(SCLK_pin, OUTPUT);   //SCLK
  pinMode(IRQ_pin, INPUT);   //IRQ
  pinMode(nSel_pin, OUTPUT);   //nSEL
}

#define IRQ_interrupt 0
void setupRfmInterrupt()
{
  attachInterrupt(IRQ_interrupt, RFM22B_Int, FALLING);
}

#endif
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

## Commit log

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2012-11-01 initial pieces of PWM RX rework started for adjustable timing
    [openLRSng.ino]
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2012-11-15 Added FAILSAFE_BEACON, this turns the RX into distress beacon after failsafe has been set for some time.
    [openLRSng.ino]
2012-11-15 rework on frequency selection... may be wrong not tested fully!!
    [openLRSng.ino]
2012-11-15 Cleaning up, beacon mode activates only after 5.5 minutes now. When beacon is sending PWM output ceases, but that should not be a problem at that point.
    [openLRSng.ino]
2012-11-30 TX: add back interrupt based PPM sampling as the ICP1 cannot be used on Flytron TX modules (pin conflict)
2012-12-10 Startting with binding stuff... not working yet.
    [binding.h, openLRSng.ino]
2012-12-16 Binding... basic config transfer working not fully verified not done.
    [RX.h, TX.h, binding.h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]
2012-12-17 - more binding changes, save EEPROM on RX - sample RSSI at correct time (when packet is on air)
    [RX.h, binding.h, common.h]
2012-12-17 Binding and randomization, update on documentation. Changed RX pin order OLD: ch1 ch2 ch3 ch4 ch5 ch6/ppm ch7 rssi ch8 NEW: rssi ch1 ch2 ch3 ch4 ch5/ppm ch6 ch7 ch8
    [RX.h, TX.h, binding.h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]
2012-12-19 Range extension: - the system now operates with servopulse range of about 800 to 2200 us - the resolution is variable i.e. 1000-2000 has 1us resolution while the extremes have 16us resolution.
2012-12-24 RX: added serial output during startup, this should make resolving bind problems easier.
    [RX.h]
2012-12-27 Added support for openLRS spectrum analyzer GUI.
    To enter spectrum analyser, connect PC to TX using a FTDI (USB2Serial) adapter and make it into binding mode (by holding the button down). The TX enter scanner mode upon receiving a hash (#) from serial line (this happens if you hit the upload button on GUI).
    [RX.h, TX.h, common.h]
2013-01-18 RX: revert back to using interrupt based PWM output, this removes the mainloop halting for 2ms during PWM output. Notable PWM pulses are now outputted in series instead of simultaneously.
    [RX.h]
2013-01-21 Update RX.h
    Possible loss of data on line 57, servoBits2Us returns 'unsigned short'
    and is being stored in an 'int'.
    [RX.h]
2013-01-23 Converted all standard c types to types defined in stdint.h.
    Performed comparisons of the hex file before and after the changes and the resulting hex was identical for both the rx and tx code.
    There were two exceptions to this. When the local fb inside 'rfmSetCarrierFrequency' and 'beacon_send' were converted to uint16_t from 'unsigned short' there was an unexplained difference in the resulting binary. Suspect some sort of type promotion by the compiler.
    fb was left typed as 'unsigned short' in both cases until the cause of the difference is investigated.
    [RX.h, TX.h, binding.h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]
2013-01-25 Formatted code with AStyle. The options chosen inside of AStyle.cfg have a lot to do with personal preference. Suggestions are welcome.
    AStyle.cfg and AStyleLuanch.bat based on work by gitsly.
    No object file changes.
    [AStyle.cfg]
2013-01-25 Modified formatting to use 1tbs.
    [AStyle.cfg]
2013-01-28 Fix regression in converting ppmOut from int8_t to uint8_t. Fixed types of some variables to reflect their usage.
    [RX.h, common.h]
2013-02-01 Fixes for Futaba compatibility. (pullup on PPM & RF out indicator)
    [TX.h, hardware.h]
2013-02-06 HW v0.1 - not finished
    [openlrsng.brd, openlrsng.sch]
2013-02-06 move TX schamatics to own repo https://github.com/kh4/openLRSngTX.git
    [openlrsng.brd, openlrsng.sch]
2013-02-13 Add possibility to reset to .ino setting instead of randomization by holding button for more than 5s (continous beep). Fix beaqcon enabling (stale #ifdef).
    [TX.h, binding.h]
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2013-02-18 Spectrum analyser mode in RX too. Short ch6 output to GND to enable it.
    [RX.h, TX.h, common.h]
2013-02-23 PPM is selected by either 1) connect MOSI to GND (on the AVRISP connector on OrangeRX receiver) - in this mode outputs CH1-CH4 = channel 1-4, CH5 = PPM, CH6-CH8 = channel 5-7 2) connect CH7-CH7 using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
    To force binding on RX connect jumpper on CH1-CH2
    To make RX act as openLRS spectrum analyser put a jumpper on CH3-CH4, LEDs stay dark in this mode.
    It is now possible to disable to "always bind" feature in the openLRSng.ino
    [RX.h, hardware.h, openLRSng.ino]
2013-02-23 Correct the combined mode (AVRISP is shared with CH6-8). 6 channels are available in combined mode as PWM.
    [RX.h]
2013-02-24 Add FORCED_PPM_OUTPUT define to make it possible to have 7 PWM channels in combined mode.
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2013-03-17 Revert "2 second watchdog timer for both TX and RX"
    This reverts commit df204293331a7b8674d344aa29e944b97159fb40.
    [RX.h, TX.h, openLRSng.ino]
2013-03-24 Fix buzzer for RX as TX.
    [hardware.h]
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2013-03-26 Binding frequency for 868 MHz modules
    [binding.h]
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2013-04-21 Typo fix for 868Mhz modules.
    [binding.h]
2013-05-12 fix +x channel outputs
    [common.h, openLRSng.ino]
2013-05-13 Fix RX output, briefly tested now and it seems to work.
    [RX.h, common.h]
2013-05-13 Fix failsafe for 16 channels.
    [RX.h, TX.h, common.h]
2013-05-14 FEAT: option to disable PPM out on failsafe FEAT: option to change failsafe delay
    [RX.h, binding.h]
2013-05-17 CRITICAL FIX for OpenLRSngTX!!
    [common.h, hardware.h]
2013-05-19 Improve PWM jitter. This modification is a bit troubling as it makes interrupt routine busyloop for about 16us, this however is just about 1-2% (depending on channel values) of CPU time so I see this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
    [RX.h]
2013-05-22 - move PPM output setting to bind_data (no more need for jumpper) - revise PWM output code to cope with upcoming HW - update scanner interface for more sane units
2013-05-23 Fix PWM outputs on Flytron v2 / OrangeRX UHF RX
    [hardware.h]
2013-06-03 RX configurator forming up.... does not work yet.
    [RX.h, TX.h, binding.h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]
2013-06-10 pin ordering fix to match new hardware
    [hardware.h]
2013-06-10 some RXconf fixing... PPM ought work now
    [RX.h, TX.h]
2013-06-19 Fix frsky telem... should work now at least RX RSSI
    [RX.h, TX.h, common.h]
2013-06-28 Semi workking, note binding send is disbled for easier work with rxconf.
    [TX.h, hardware.h]
2013-06-28 Make PWM/PPM disabling synchronous so that no corrupt PPM frames are generated.
2013-06-28 . allow using serial pins as PWM outputs - optimize EEPROM write by not writing if data is correct already
    [RX.h, binding.h, hardware.h]
2013-06-29 Enable two way binding. TX will stop transmitting bind packets once RX acknowledges bind. This allows detecting successfull bind without looking at the RX leds.
    Sending of bind packets can be resumed by pressing button on TX.
    [TX.h]
2013-06-29 - do not limit packet rate - misc fixes
    [binding.h, common.h]
2013-06-29 Fix FrSky telemetry (memory corruption bug).
    [frskytx.h, openLRSng.ino]
2013-06-29 - fix some menu types - default minimum PPM sync to 3000 us (tunable 2500-10000)
    [binding.h]
2013-07-11 Fix PPM input by pin change interrupt.
    [hardware.h]
2013-07-11 - Revised RX logic for failsafe / beacon, it is now separate from lost packet counter and based on time only. - Allow setting of failsafe delay via CLI (0.1 - 25.5s)
    [RX.h, TX.h, binding.h]
2013-07-11 Fix FrSky RSSI scales (TX=0-255 // RX=0-127).
    [frskytx.h]
2013-07-11 RX: ability to limit PPM output to 8ch (for incompatible FCs)
    [RX.h, binding.h, openLRSng.ino]
2013-07-12 second RSSIpwm fix, thanks readerror
    [RX.h]
2013-07-20 small copypaste fix :P
    [hardware.h]
2013-07-30 ngTx updates; add RFOUT for futaba module and add pin for RFM SDN (just pulled low by code for now)
2013-08-06 Quick fix for the "NO DATA" blinkking problem on some er9x/opentx versions.
    [frskytx.h]
2013-08-07 Fix PPM channel limit
    [RX.h]
2013-08-08 EEPROM robustness
    Move data 256 bytes back on EEPROM as suggested.
    Verify EEPROM writes, continued failure will halt the module and just blink in "two pulse" pattern.
    [RX.h, binding.h, common.h]
2013-08-08 'RCHacker' style outputs on RX as TX. I.e. there is a variable tone buzzer and LEDs available on the servo headers. Speaker via transistor to 'port 1' Red LED to port 6 Green LED to port 7
    Please note that if you left PPM connected to port1 to allow using flytron/thundead code you must remove it now.
    [TX.h, hardware.h]
2013-08-09 BUGFIX: bind randomize fix with 24 channels active, thanks to englishman for spotting this out
    [binding.h]
2013-08-15 add missing call ;)
    [TX.h]
2013-08-19 ome intitial master-slave stuff, using Wire (bleh) likely going to rewrite with lower level I2C access to avoid multiple buffer layers.
    [RX.h, hardware.h, openLRSng.ino]
2013-08-22 Add 'LBEEP' code. This allows the RSSI pin to be used for audible beeps on packetloss via FPV audio link without any extra hardware.
2013-08-22 Fix RSSI during packetloss (broken by LBEEP code)
    [RX.h]
2013-09-13 Removing I2C access functions, going to use own I2C library instead of Wire.
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2013-09-24 Add testcode behind defines: TEST_NO_ACK_BY_CH0 - do not reply from RX in case ch0 > ~1900 TEST_DUMP_AFCC - dump AFCC offsets on TX (needs telemetry)
2013-11-04 Fix 6ch LEDs
2013-11-19 Detach failsafe/PWMstop/PPMstop timeouts.
2013-11-19 Raise binding power to avoid trouble with some rfm23bp:s
    [binding.h]
2013-11-19 refactor, excConnect (avoid dupped code)
    [binary_com.h]
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2013-11-19 fix 6ch defaults to match pin swap
    [binding.h]
2013-11-20 Fix smartPort CRC, tested to work, enjoy.
    [frskytx.h]
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2013-11-20 Allow muting of TX buzzer on telemetry loss.
    [RX.h, TX.h, binding.h]
2013-11-21 Add feature to enable outputs on RX before link (needs failsafes set). Also load failsafe values from EEPROM during startup.
    [RX.h, binding.h]
2013-11-21 Fix smartPort RSSI value range. Fix failsafe copy (type clash)
    [RX.h, frskytx.h]
2013-11-21 Cleaning up, use timing based on us/ms depending on needed resolution. This is to avoid overflowing on long intervals.
    [RX.h, binding.h]
2013-11-22 Make jumpper detection pulses short to avoid confusing some ESCs.
    [RX.h]
2013-11-23 Encode RF channel number into RFmagic, this will prevent RX from syncing to wrong slot in hop sequence when channels are overlapping.
    [common.h]
2013-11-24 Revert beacon interval to linear. Add check for correct rxtype in rxconfig.
    [RX.h, binding.h]
2013-11-26 Fix telemetry on 4+4 (a stupid bug....)
    [binding.h, frskytx.h]
2013-11-28 Fix failsafe after saving.
    [RX.h]
2013-11-28 Fix servo RSSI to be same as analog.
    [RX.h, openLRSng.ino]
2013-11-28 other place to fix...
    [RX.h]
2013-11-29 Fix possible loading of failsafes due to out-of-order time assignment
    [RX.h]
2013-11-29 Fixup RSSI PWM
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2013-12-07 Remove microPPM autodetect and and flag to enable microPPM and/or inverted PPM.
    [TX.h, binding.h]
2013-12-07 Fix microPPM flag polarity (division needed on normal (not micro) PPM).
    [TX.h]
2013-12-17 Add 'active' buzzer suport for 6ch RX as TX
    [hardware.h]
2013-12-18 Profile support. Factory reset by keeping bind button down > 10s is now changed to be 'profile swap' i.e. alternate configuration is activated on the TX. Active config is indicated by number of beeps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
    [TX.h, binding.h]
2013-12-19 Fix profile activation to be correctly done without need to restart TX.
    [TX.h]
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2013-12-19 Fix PSP profile changing
    [binary_com.h]
2013-12-30 revisit the RSSI implementation
    This changes the behaviour to make a clear difference between RSSI
    and link quality.
    Composite RSSI now shows RSSI when linkquality is perfect as output
    values of 80-100%.
    If quality is degraded the composite output will switch to pure
    quality as 0-75%.
    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
2013-12-30 rework TX side RSSI too
    [TX.h]
2013-12-31 Add EditorConfig configuration
    EditorConfig is a cross plattform/editor plugin to help enforce a
    coherent coding style (i.e. line endings, no trailing whitespace,
    indentation etc) and supports a load of editors/ides.
    See http://editorconfig.org/#download for your the plugins.
    For now I set the encoding to utf-8, linux style line endings,
    indentation of 2 spaces, insertion of final newline and enabled the
    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
2014-01-21 Fix framesize (only 7 channels), tested with baseflight.
2014-01-21 Allow using compilers from system location, if they are not part of Arduino install (e.g. on Fedora)
2014-01-22 Implement slaveRX recovery after failure.
    [I2C.h, RX.h]
2014-01-23 Makefile improvements Fix srandom zero check
    [TX.h, binding.h]
2014-01-30 Fix SBUS flags (packetloss and failsafe)
    [RX.h]
2014-01-31 Fix SBUS on both TX and RX side.
    [TX.h]
2014-01-31 Fix parity to even on SBUS output
    [RX.h]
2014-02-01 reset needle on request (not automatically)
    [common.h]
2014-02-05 fix slave led
2014-02-08 fix little bug in PPM validation
    [TX.h]
2014-02-10 Clearer LED bahaviour when in PSP (configurator), CLI and spektrum modes. In all of these both LEDS are lit.
2014-02-12 Add LLIND functionality. LLIND is binary linkstate output (high when link problems are occurring).
    [RX.h, hardware.h]
2014-02-12 Fix specialstr arrray content.
    [hardware.h]
2014-02-13 Fix SUMD byte order.
    [TX.h]
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2014-02-16 Fix LED bahaviour on scannerMode
    [RX.h, common.h]
2014-02-21 Fix LLIND and switched outputs
    [RX.h]
2014-03-12 Loosen up validation for spektrum satellite packet.
    [TX.h]
2014-03-12 Add PSP methods for editing failsafe on RX.
    [RX.h, binary_com.h]
2014-03-12 Transfer failsafe as us (on PSP)
    [RX.h, binary_com.h]
2014-03-12 PSP fixes for failsafe
    [RX.h, binary_com.h]
2014-03-12 fix PSP failsafe save
    [RX.h]
2014-03-12 move save routine below tx reply to avoid delays
    [RX.h]
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2014-03-18 Fix byteorder for failsafe
    [RX.h]
2014-03-18 Fix failsafe editing via configurator
    [RX.h, TX.h, binary_com.h]
2014-03-18 Change WD to 8 seconds Remove forced delay on failsafe saving.
    [RX.h, TX.h]
2014-03-24 Fix check for Leonardo bootloader enter. (one should not code when too tired)...
2014-03-27 bugfix for psp save tx_config (missing break)
    [binary_com.h]
2014-03-28 Clean up makefile output - hide output from library compile - hide commands Remove the unneeded array declarations from binary_com.h Fixup Serial.begin() warning on Leonardo
    [TX.h, binary_com.h, binding.h]
2014-04-04 bugfix for last commit
    [binding.h]
2014-04-05 adding optimized CRC-16 function to binding.h
    [binding.h]
2014-04-06 Revert "adding optimized CRC-16 function to binding.h"
    This reverts commit f6d2c3f45e86d43c098de3cefea6fce0fa3d05cc.
    [binding.h]
2014-04-06 debugging wrong CRC value
    [TX.h, binary_com.h, binding.h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]
2014-04-06 moving stuff around to binding area
    [TX.h, binding.h, common.h]
2014-04-06 adding new eeprom calls to RX as well
    failsafe is read/write is still missing
    [binding.h]
2014-04-06 initial hooks to new eeprom in failsafe functions
    [RX.h]
2014-04-07 Redo failsafe eeprom routines. Some optimizations on codesize i.e. "static inline" for funcs used once.
    [RX.h, TX.h, binding.h]
2014-04-07 Enable eeprom access for failsafePPM
    [binding.h, common.h]
2014-04-07 populate EEPROM duplicates, no recovery of failed blocks yet
    [binding.h]
2014-04-07 fix number of copies to write...
    [binding.h]
2014-04-08 fixing indentation, removing obsolete code
    [binding.h]
2014-04-09 bugfix for addressBase and addressNeedle
    [binding.h]
2014-04-09 invalidate failsafe on restore default
    [RX.h, binary_com.h]
2014-04-09 addressNeedle needs to be properly reset, period
    [binding.h]
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2014-04-10 Fix lockout on overflow of Telemetry buffer (TX side)
    [TX.h]
2014-04-17 Lower I2C speed to 200kHz as 400kHz is unreliable with longer lines.
2014-04-19 Reorganize flags and fix duplicate watchdog/microPPM flag
    [binding.h]
2014-04-25 Optiomized optiboot with EEPROM support. This is needed for openLRSng to utilize watchdog on atmega328p based boards.
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2014-05-07 Modifying the buzzer, simple high or low. Moving the BTN to SCL so a normal jumper can be used to enter BIND mode if used as TX.
    [hardware.h]
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2014-05-20 Fix signal monitor values.
    [binary_com.h]
2014-05-22 Make use of the SDN pin on supported hardware; required for JRdTX due to long electrical startup time
2014-05-26 Fix RXD/TXD as normal output.
    [RX.h]
2014-08-12 Fix RSSI PWM frequency.
    [RX.h]
2014-08-18 Minimize time with interrupts disabled, this should solve issues with PPM glitching with OrangeRX/Flytron gear.
    [TX.h, binary_com.h]
2014-08-27 Rename miniRX to microRX to avoid confusion with the 6ch with USB.
    [binding.h, hardware.h]
2014-08-27 Fix RX ID numbers
    [hardware.h]
2014-08-30 Add 'static beacon' mode, emit single tone for 20s at full power in place of fading tune.
2014-09-14 Bug fix for operation with slave present. More clear LED behaviour with slave.
    [RX.h]
2014-09-15 Adding 'AltPower' mode, this makes every n:th packet sent at lower power.
2014-09-21 Fix Flytron M1 pins
    [hardware.h]
2014-10-10 Fix ppmChannels going to 17 when 16ch is used without RSSI injection.
    [RX.h]
2014-10-10 Fix serial output with SPEKTRUM, SUMD and SBUS.
    [RX.h]
2014-10-25 Fix Sx outputs. - failsafe did not apply to them - the outputs only worked when telemetry was enabled
    [RX.h]
2014-10-25 Make Sxx thresholds vary between outputs
    This allows using one channel to control up to three separate
    switches in following manner. The threshold is determined by
    modulo of the output number, it is advisable to test the outpus
    to verify order.
    input | SXa | SXb | SXc
    -1166 | OFF | OFF | OFF
    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
2014-10-31 Correct packet length with diversity (extra 5 bytes of preamble) Allow recevery from TX timeout.
    [TX.h, common.h]
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2014-12-08 Revise profile selection and minor cleanup o simplify logic a bit, allow selection of 'hw' mode via push button o move HW specific rx_config init to hardware.h
2014-12-08 Profile cleanup o new PSP:s for setting default profile. o add 'boost' switch support Signed-off-by: Kari Hautio <khautio@gmail.com>
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2014-12-09 Support enabling failsafes on per channel manner.
    [RX.h, binding.h]
2015-01-01 Remove dead code on frsky (smartPort) CRC routine.
    As per https://github.com/opentx/opentx/issues/1960
    [frskytx.h]
2015-01-02 Initial support for locking failsafes from modification by 'button save'.
    [RX.h, binding.h]
2015-01-04 RX: Add support for triggering beacon sequence externally
    Code samples RSSI on beacon frequency during hops when in failsafe
    state. If RSSI exceeds average by more than 10dB beacon sequnce is
    fired after 1 second.
    [RX.h, common.h]
2015-01-19 Adaptive randomization should work now
    Rest of implementation added and enabled storing to eeprom. Some
    debug prints still present and should be removed after correct
    operation is confirmed.
    [TX.h, binary_com.h, binding.h]
2015-01-19 Also obey maxfreq on pure randomization (type promotion fail)
    [binding.h]
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2015-01-30 Fix mode switch reading code.
    [TX.h]
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2015-03-18 Fix profile to defaut to '1'.
    [binding.h]
2015-03-19 Fix critical issue in channel mapper
    Thanks for acc007@RCGroups for reporting and providing patch.
    [TX.h]
2015-04-04 Add mode switch support for flytron/orangeRX HW (version 3.8.3)
    TX (type 2) CPU pins PD5 and PD6. Connect switch to PD5 GND PD6.
    RX (type 3) switch should be connected to: output8 GND output9.
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2015-05-20 Add 'hardcoded' inputs to TX side channel mapper.
    This feature allows channels to be hardwired to specific values on
    TX, this may be usable along with failsafes set via RX conf. For
    example it allows ch7 being used as failsafe state with 6ch radio.
    [TX.h]
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2015-09-25 SBUS TX input: Fix off-by-one frame error, and prevent the SBUS decoder from 'locking on' to an incorrect start byte in the frame.
    [TX.h]
2016-01-07 Telemetry: do not send frsky telemetry frames on linkloss
    Fixes #96
    [TX.h]
2016-01-22 binary_com: make 'PPM_INVERT' setting work immediately
    This change enables the change of the 'PPM INVERT' flag without rebooting the board.
    [binary_com.h]
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2016-02-25 SBUS RX output: Fix correct number of stop bits for SBUS output
    [RX.h]
2016-10-06 sbus: fix frame length & add serial config
    [TX.h]
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2016-12-13 Fixes for PPM, PPM init delay.
    [TX.h]
2016-12-15 Fixed build for boards with console serial.
    [TX.h]
2017-02-27 Reset beacon after relink
    Previously beacon was not fully disabled and the RX listened for
    beacon trigger briefly after first packet causing the second
    packet being lost as it missed the preamble (third was received OK).
    [RX.h]
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2018-01-05 fix BOARD_TYPE label for TX startup message
    [TX.h]
2018-01-05 extend watchdog timer for lost-model beacon
    Temporarily set watchdog to 4sec within beacon routine to avoid timing
    out & resetting the RX (for watchdog-enabled RX's)
    This commit fixes #146
    [common.h]
2018-01-10 Extend PMR446 channel range to 16 channels
    Per ECC Decision (15)05, effective January 2016, PMR446 channel range
    was extended from 8 to 16 channels for analog operation. This fix
    reflects that change. This also references/partially fixes #105
    [binding.h]
2018-01-10 add TX module configuration baud rate setting
    this adds an additional baudrate setting to the tx_config, allowing for
    connecting to the CLI/Configurator with a user-selected baudrate
    (instead of hard-coded 115200 baud)
    This resolves issue #141
    [TX.h, binding.h]
2018-01-10 add support for inverted PPM output
    this adds flags & logic for inverted PPM output on RX
    [RX.h, binding.h]
2018-01-11 Fixed PPM signal monitor.
    [TX.h, binary_com.h]
2018-01-11 Fixed warning in `RX.h`.
    [RX.h]
2018-01-22 fix start-up timing issue for 32u4
    add a start-up delay to mimic standard bootloader in order to allow
    Configurator time to detect boot message
    [TX.h]
2018-01-22 add support for binary proto on RX side. also, removes RX 'scanner mode' set by pin jumper (no longer needed)
    [RX.h, binary_com.h, openLRSng.ino]
2018-01-26 Layout change to conform to Arduino IDE requirements
    -Renamed "src" dir to "openLRSng" and associated path references
    -Minor fix for leonardo description in PIO config
    -Key source directory off of platformio.ini config file for build scripts
    -Readme to root directory
    [I2C.h, RX.h, TX.h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]
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2018-01-27 fix bindmode ACK for TX
    [TX.h]
2018-01-31 RX.h refactor, misc. clean-up / fixes
    [RX.h, binary_com.h, binding.h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]
2018-02-01 fix binaryMode() prototype & definition in RX.h
    [RX.h]
2018-02-07 - reorganize RFM code, fix prototypes, fix RFM 'READY' mode setup - add include conditional statements - move time scaling functions to common.h
    [I2C.h, RX.h, TX.h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]
2018-02-09 fix SBUS input scaling for TX (using FrSky scaling)
    [TX.h]
2018-03-29 add hop channel check into packet header
    revert to original logic of adding xor'ed RF magic value into check
    header based on current hop channel number
    [common.h]
2018-04-09 fix broken RX->TX serial bridge connection
    add missing rx_reset() call to fix broken telemetry packet handling on
    TX side. Without rx_reset() call, the received packet handler routine
    will incorrectly run on each loop iteration. This breaks the incoming
    serial packet handling.
    [TX.h]
2018-04-10 fix telemetry packet interval
    for some reason, I mistakenly changed the offset value for telemetry
    packets. This reverts it to the original value & fixes backward
    compatibility with previous firmware versions.
    [common.h]
2018-07-06 Update outdated PIO platform parameters
    `board_f_cpu` option is deprecated and will be replaced with `board_build.f_cpu` in next release.

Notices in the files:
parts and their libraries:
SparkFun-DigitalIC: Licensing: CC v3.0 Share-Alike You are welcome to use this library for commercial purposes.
